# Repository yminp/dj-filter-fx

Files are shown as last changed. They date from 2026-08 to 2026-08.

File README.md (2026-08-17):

# dj-filter-fx
A voltage-controlled DJ filter unit with LFO-like envelope function

## Disclaimer
This design has not yet been validated with a physical prototype. The schematic has been reviewed and analyzed, but practical issues may still be discovered during assembly and testing. A prototype is planned to be built and tested soon.

Anyone building the current revision should treat it as an experimental, pre-prototype design rather than a fully validated production circuit.

## Description
This project is a standalone analog filter effects unit intended primarily for DJ use.

The motivation came from the relative lack of dedicated standalone filter FX units for DJs. Filter effects are built into most modern DJ mixers, but older analog mixers may not provide an integrated filter effect. In those cases, applying a filter generally requires an external effects processor connected through the mixer's send/return path. The goal of this project is therefore to provide a dedicated external filter effect that can be used with such mixers while retaining an analog signal path.

Another major purpose of the project was educational. I wanted to explore the use of operational transconductance amplifiers (OTAs), particularly the LM13700, as voltage-controlled amplifiers (VCAs). In this design, VCAs are used inside a state-variable filter to provide voltage control of both the filter's center frequency and resonance Q. This required treating the OTA not merely as a conventional variable-resistance element, but as a controllable transconductance stage whose gain can be incorporated into the state-variable filter equations.

The project consequently combines several topics that I wanted to study in a practical audio circuit:

- voltage-controlled state-variable filters;
- LM13700 OTA/VCA design;
- voltage control of cutoff frequency and resonance;
- envelope-controlled filtering;
- LFO-based filter modulation;
- analog switching and filter-mode selection;
- balanced audio input and output interfacing;
- gain structure and headroom for professional/DJ audio levels (accepting input up to +26dBu, balanced).

The design is intended both as a usable DJ effects unit and as an experimental platform for learning analog filter and voltage-controlled amplifier design.

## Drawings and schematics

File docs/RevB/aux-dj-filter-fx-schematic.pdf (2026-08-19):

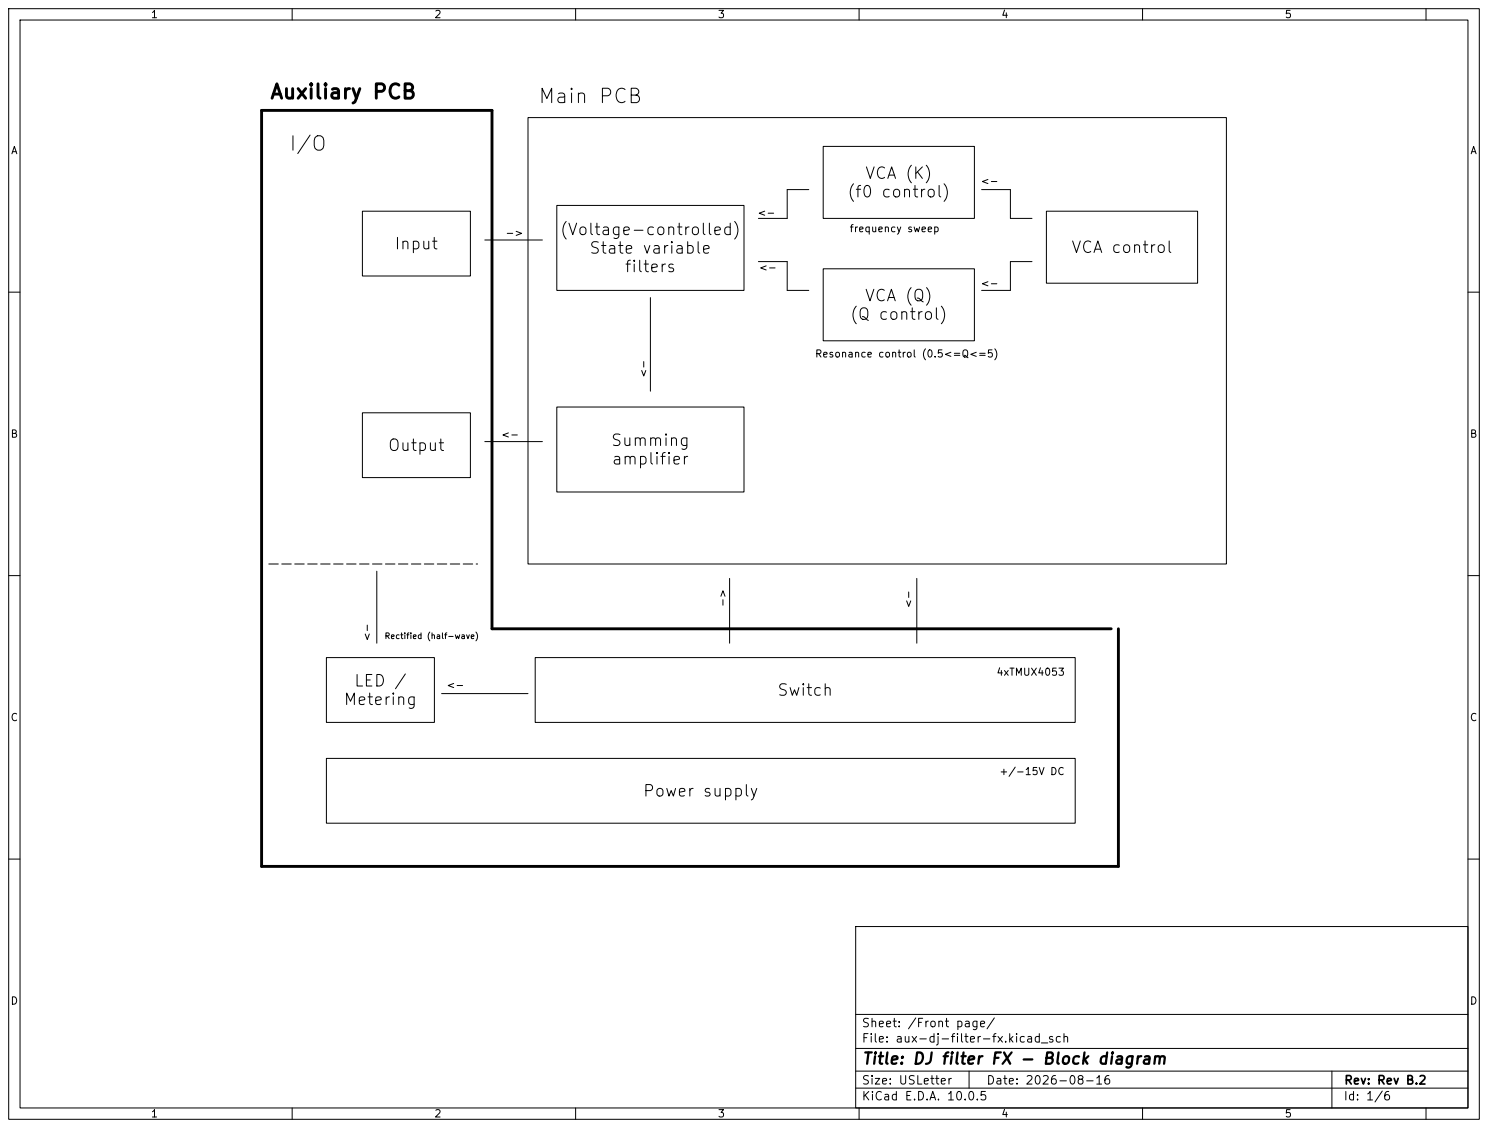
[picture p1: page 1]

Sheet: /Front page/
File: aux-dj-filter-fx.kicad_sch
Title: DJ filter FX - Block diagram

Size: USLetter | Rev: Rev B.2
KiCad E.D.A. 10.0.5 | Id: 1/6

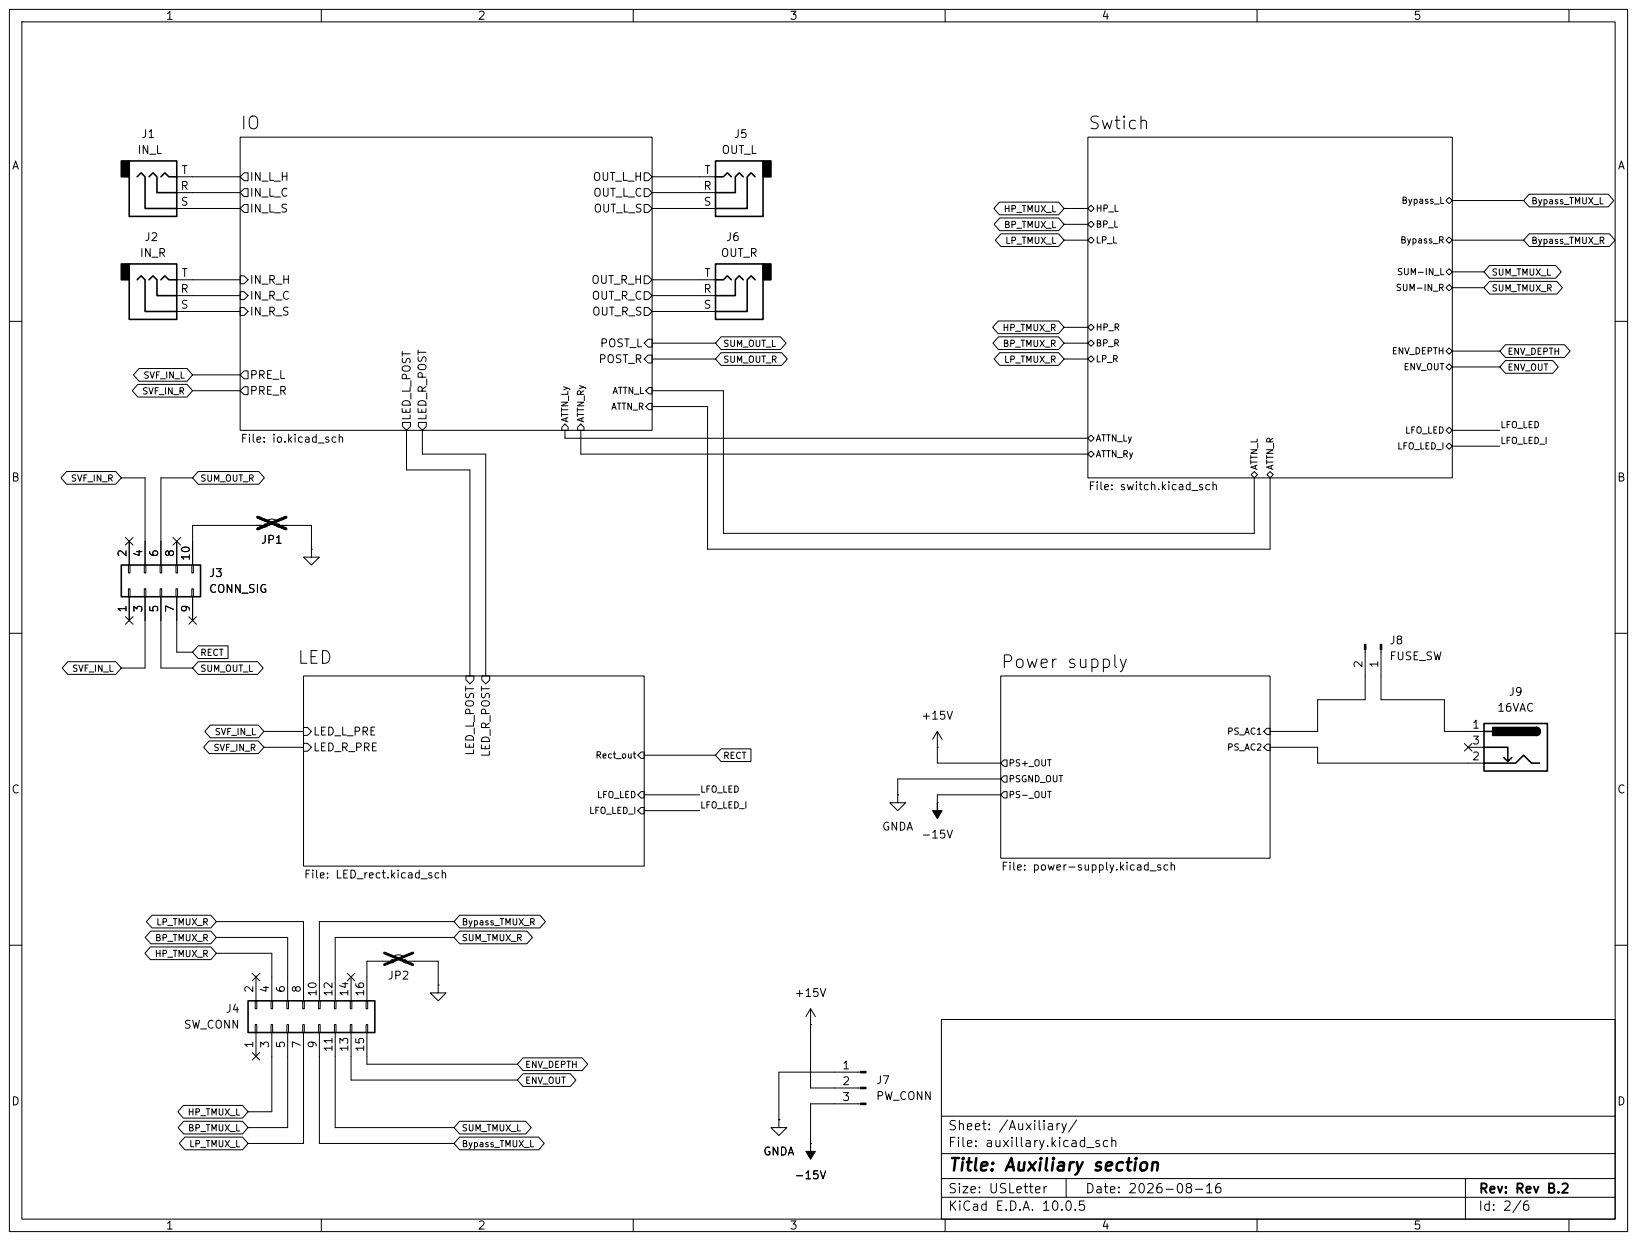
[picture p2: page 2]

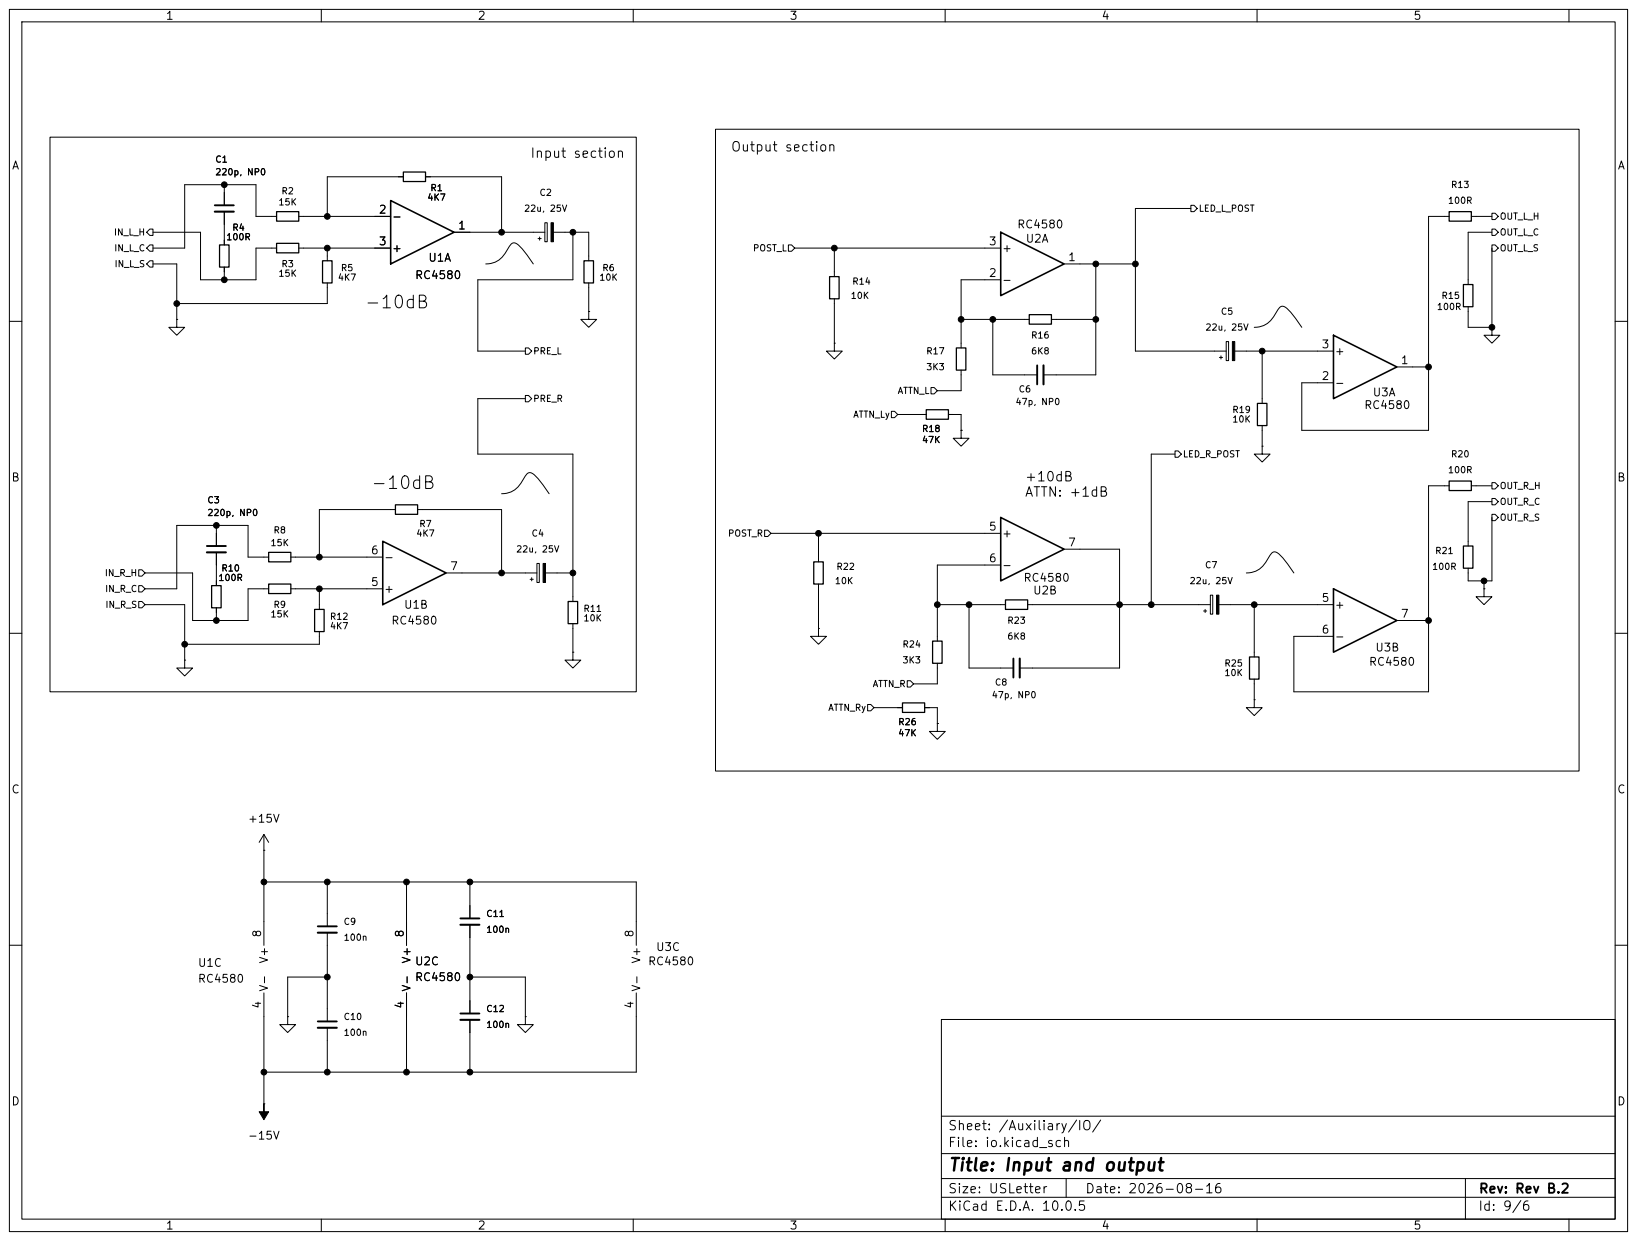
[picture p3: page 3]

File: io.kicad_sch
Title: Input and output

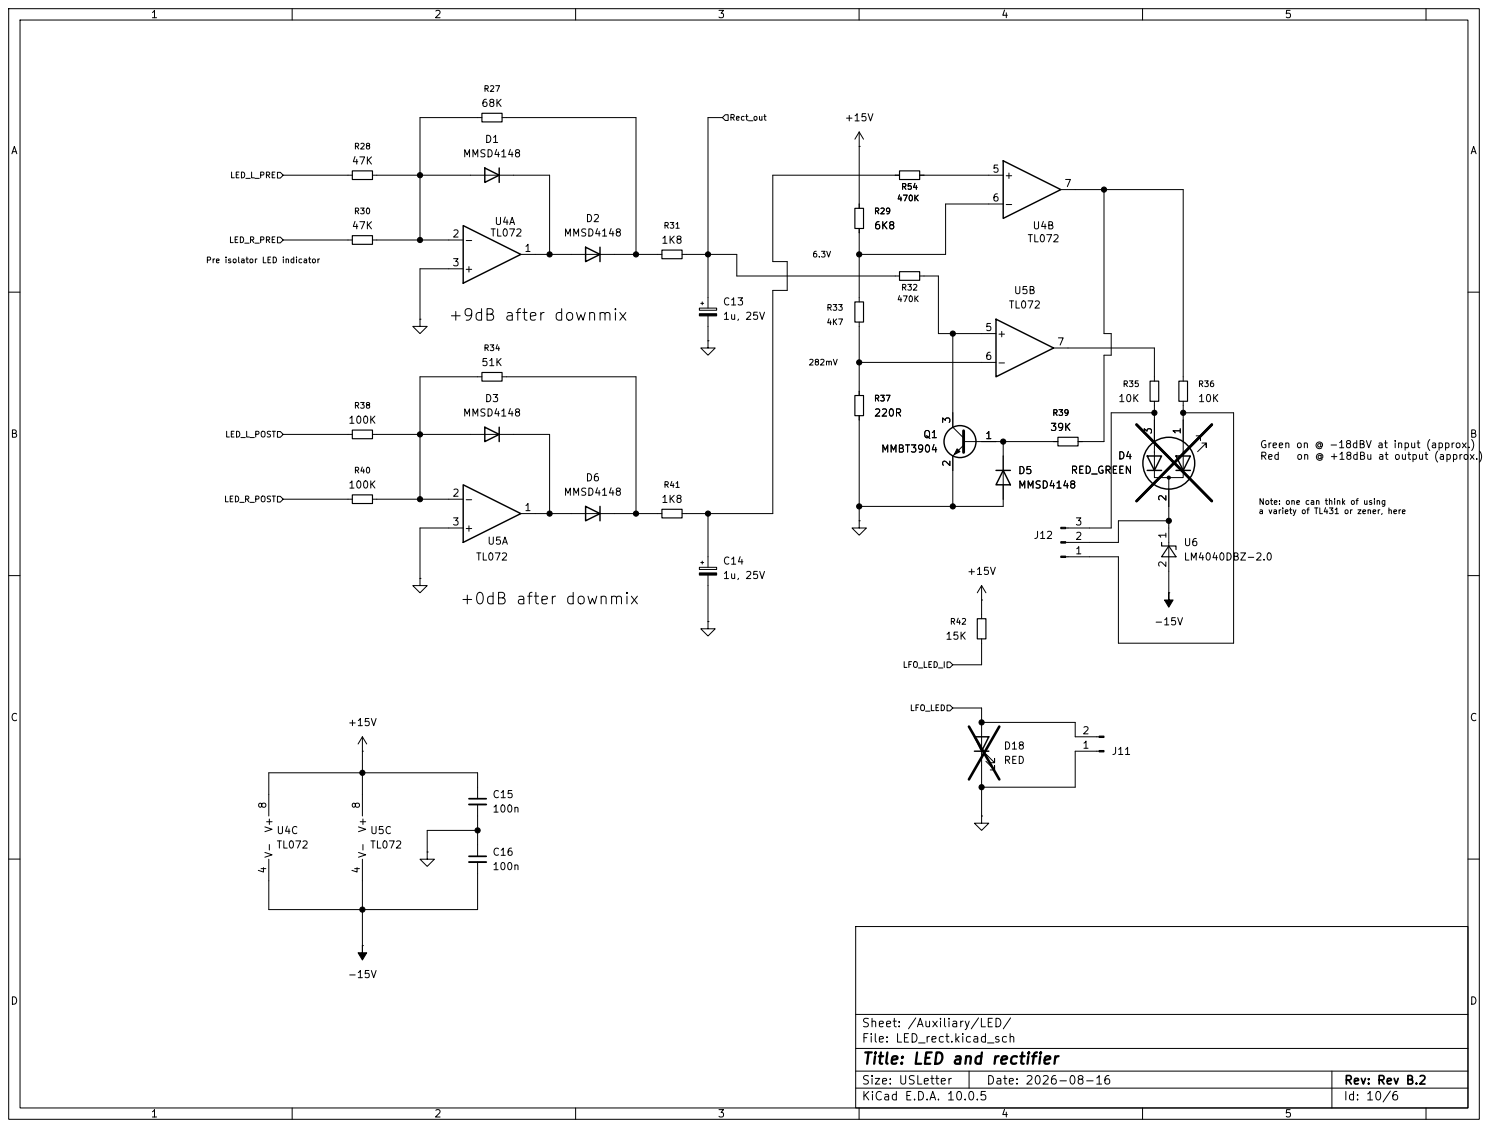
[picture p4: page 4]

File: LED_rect.kicad_sch
Title: LED and rectifier

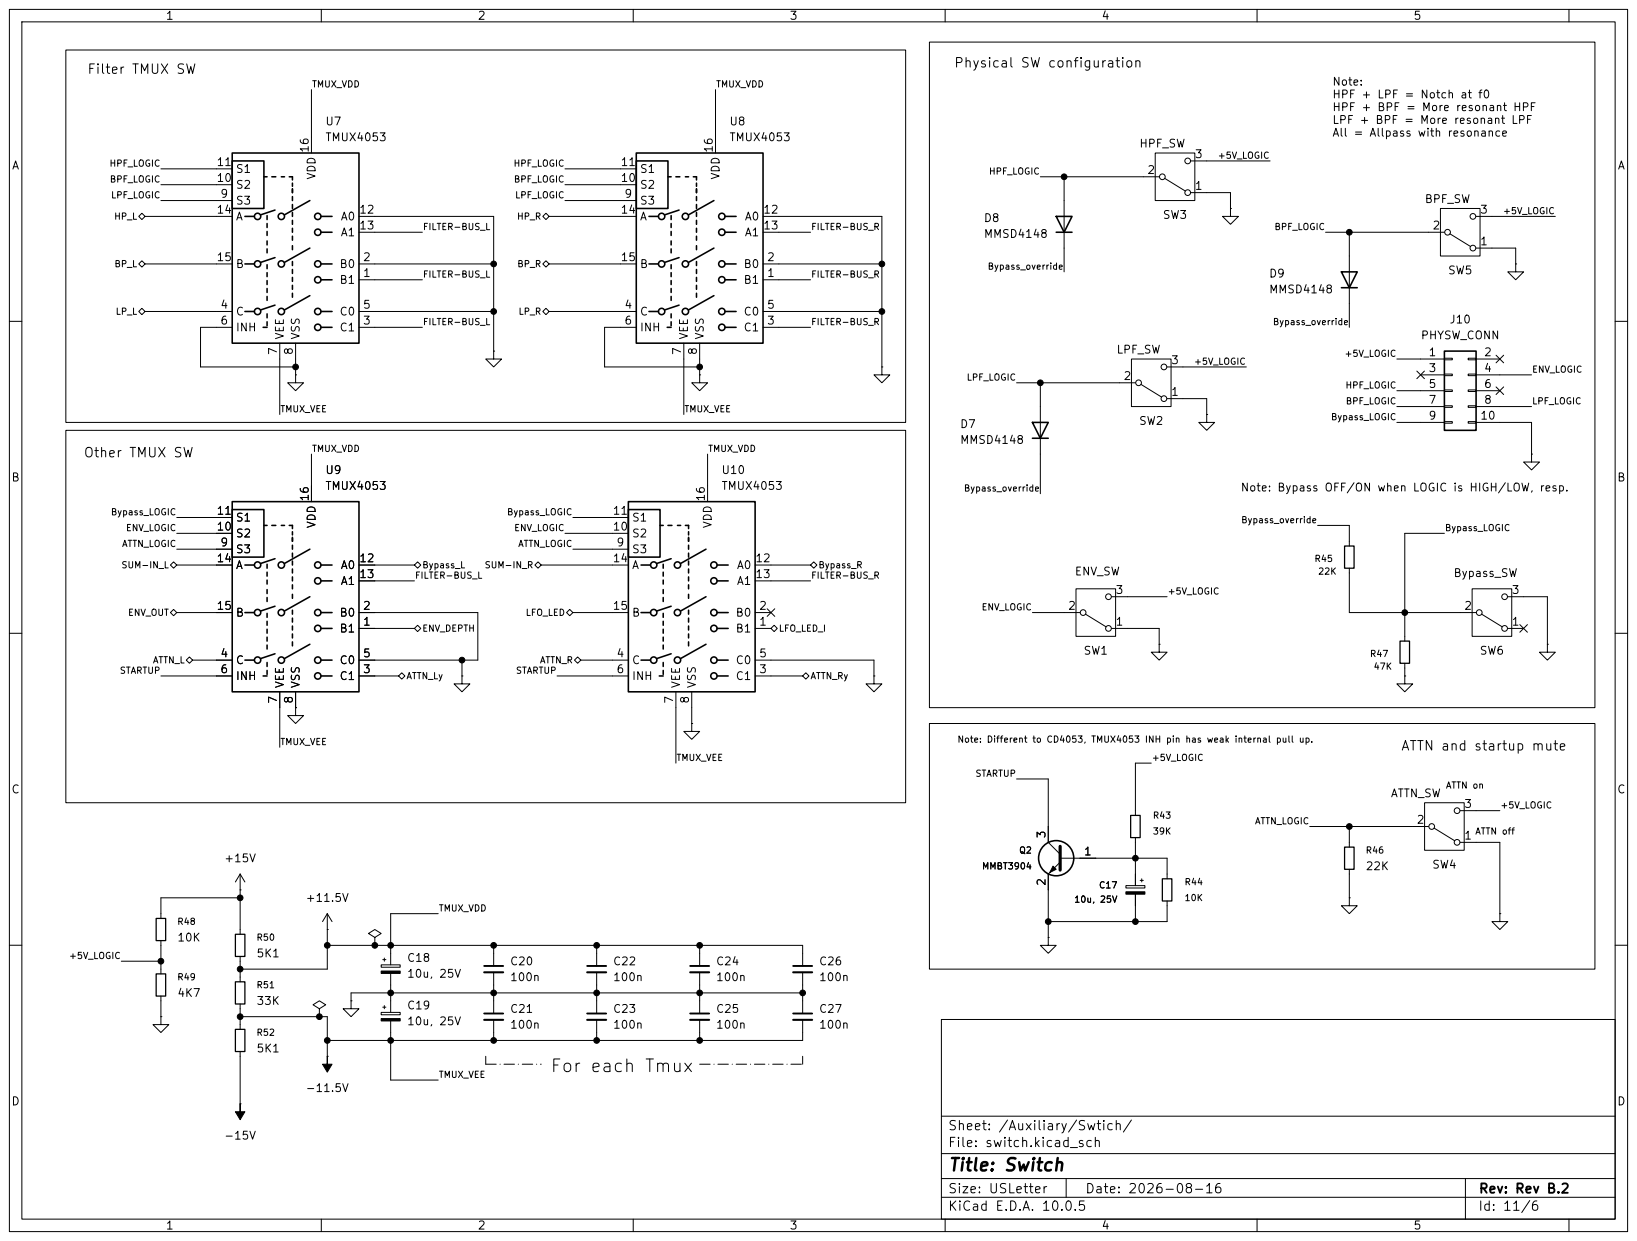
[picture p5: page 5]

Note: HPF + LPF = Notch at f0 HPF + BPF = More resonant HPF

All = Allpass with resonance Note: Bypass OFF/ON when LOGIC is HIGH/LOW, resp. C17

LPF + BPF = More resonant LPF

Note: Different to CD4053, TMUX4053 INH pin has weak internal pull up.

ATTN and startup mute

ATTN off ATTN on For each Tmux

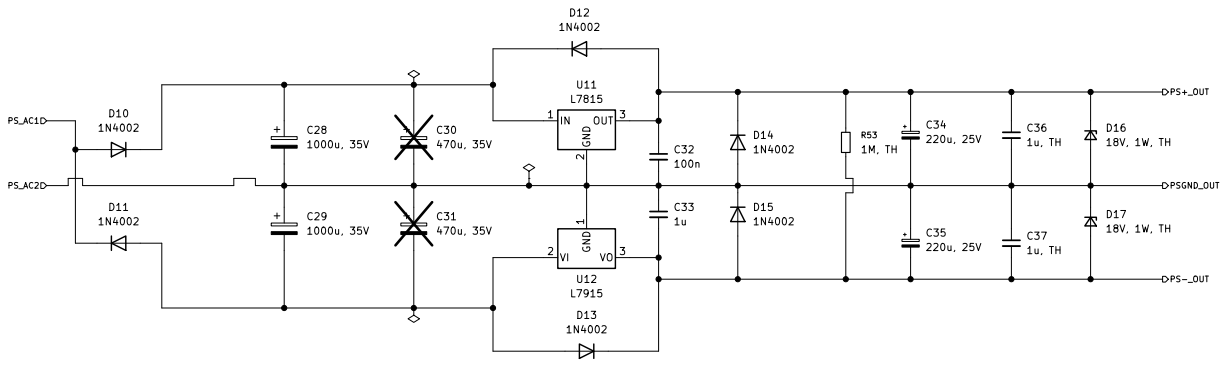
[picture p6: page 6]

Sheet: /Auxiliary/Power supply/
File: power-supply.kicad_sch
Title: Power supply

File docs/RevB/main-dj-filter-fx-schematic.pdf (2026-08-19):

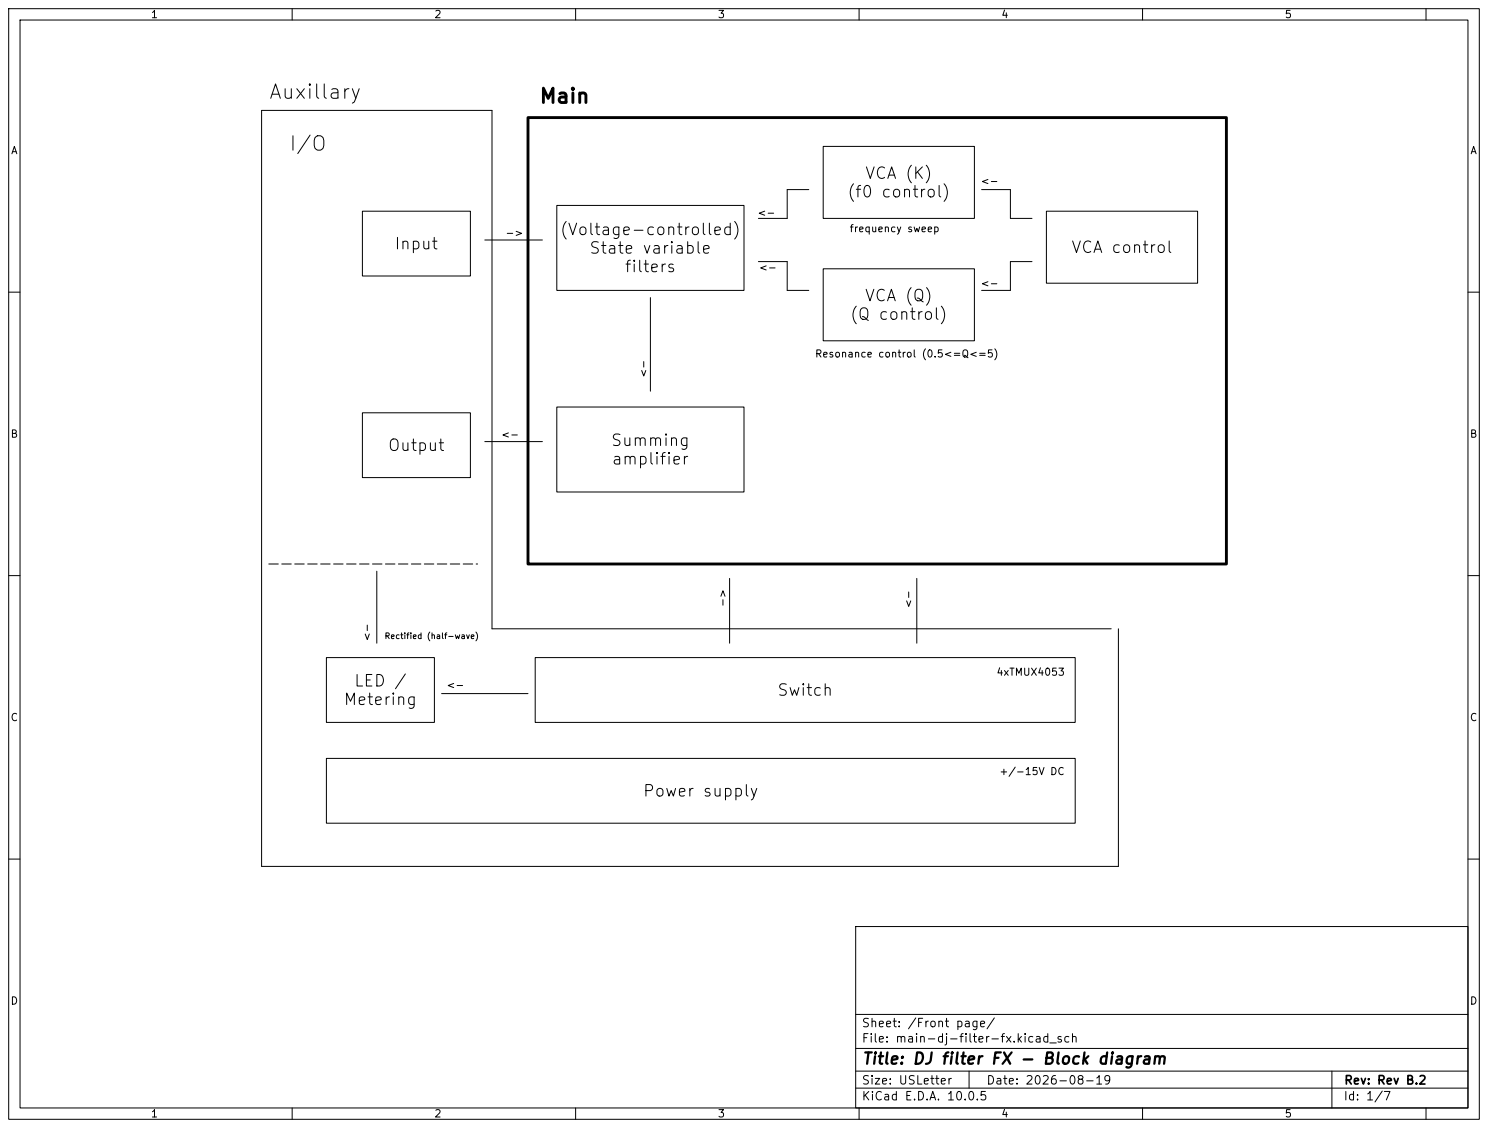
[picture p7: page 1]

Sheet: /Front page/
File: main-dj-filter-fx.kicad_sch
Title: DJ filter FX - Block diagram

Size: USLetter | Rev: Rev B.2
KiCad E.D.A. 10.0.5 | Id: 1/7

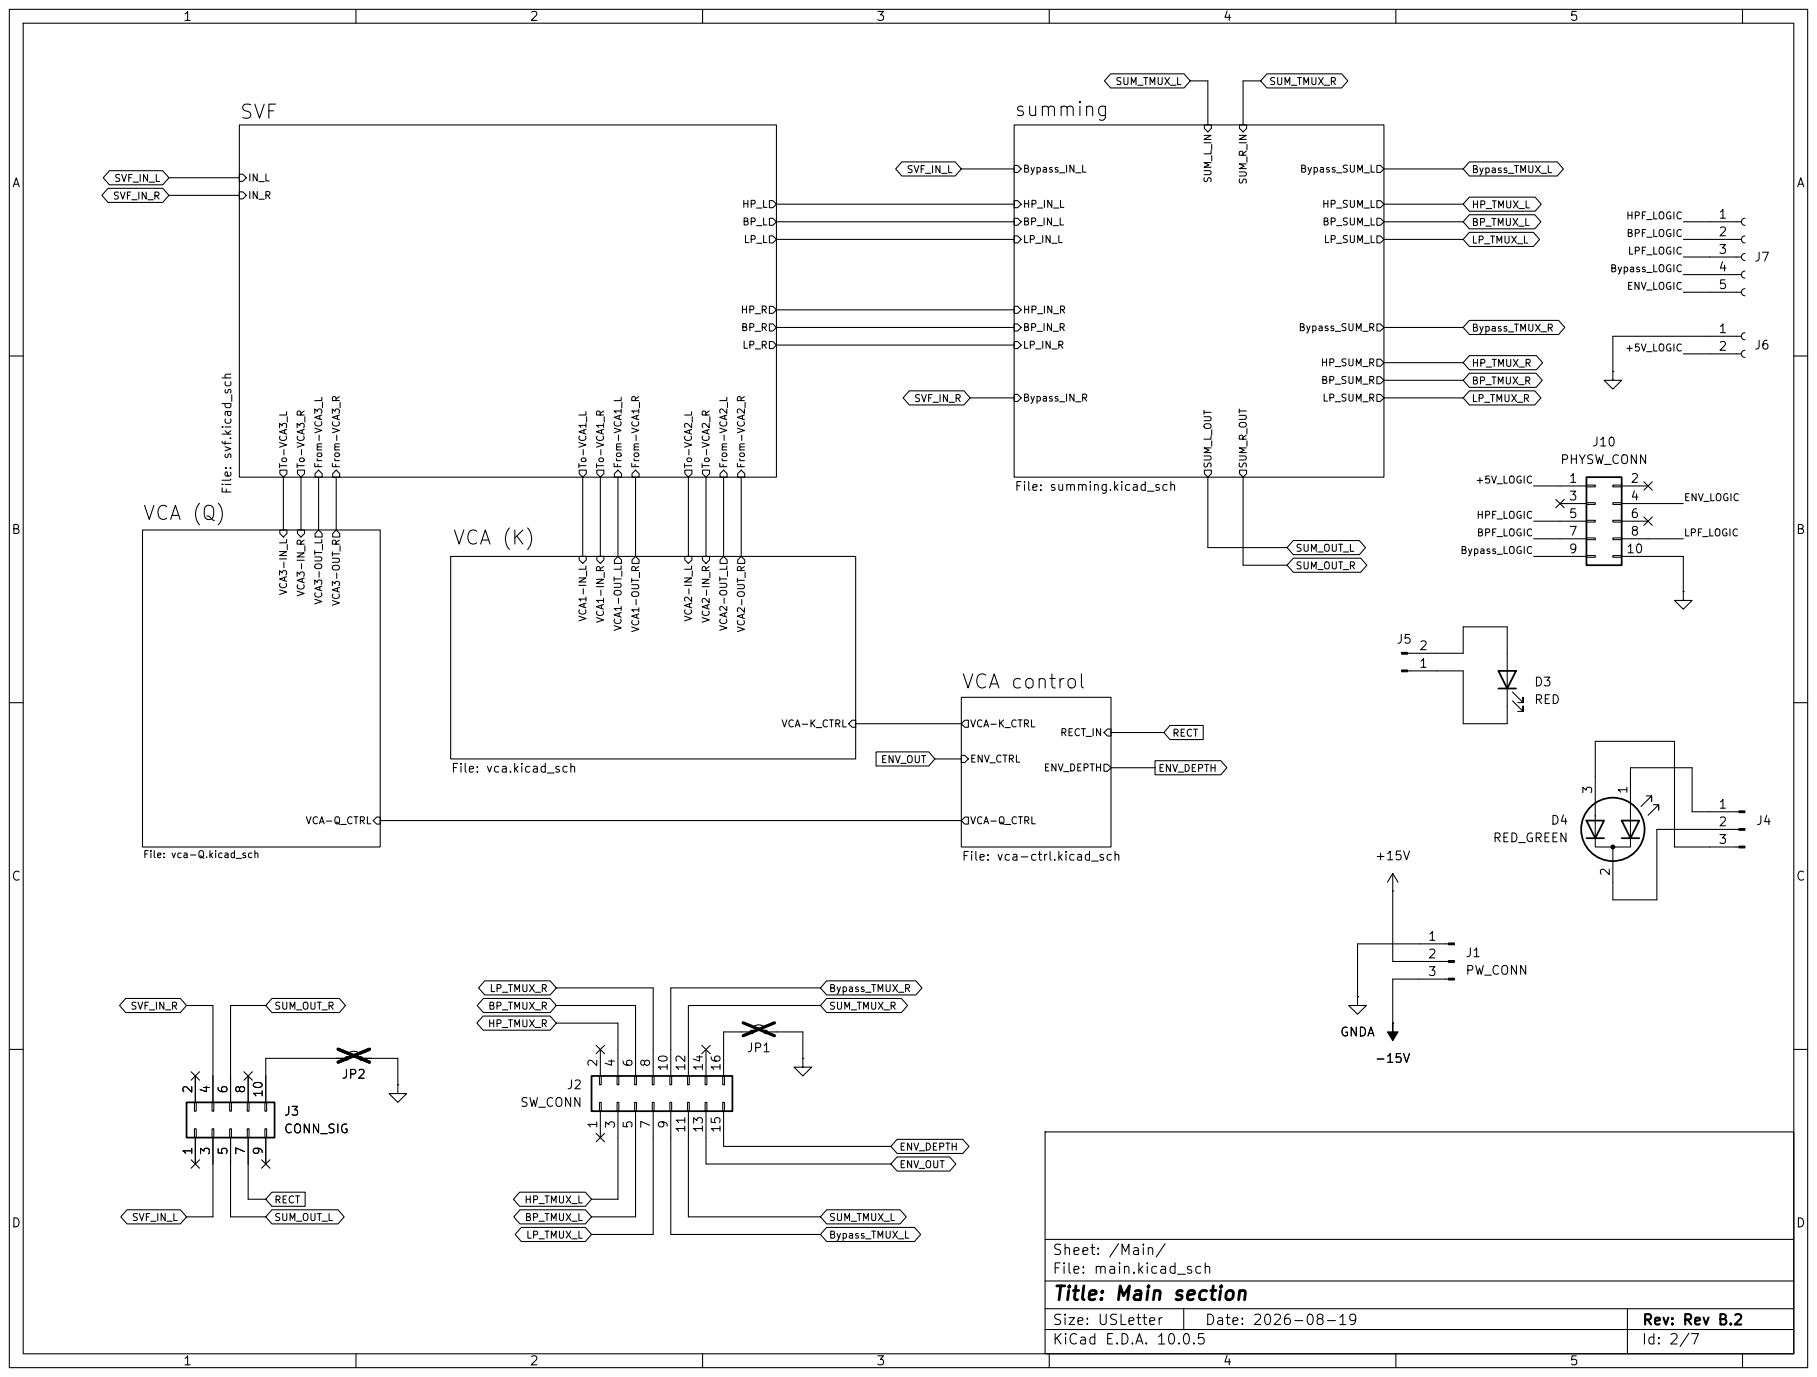
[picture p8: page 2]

RECT_IN VCA control File: vca-ctrl.kicad_sch
ENV_OUT

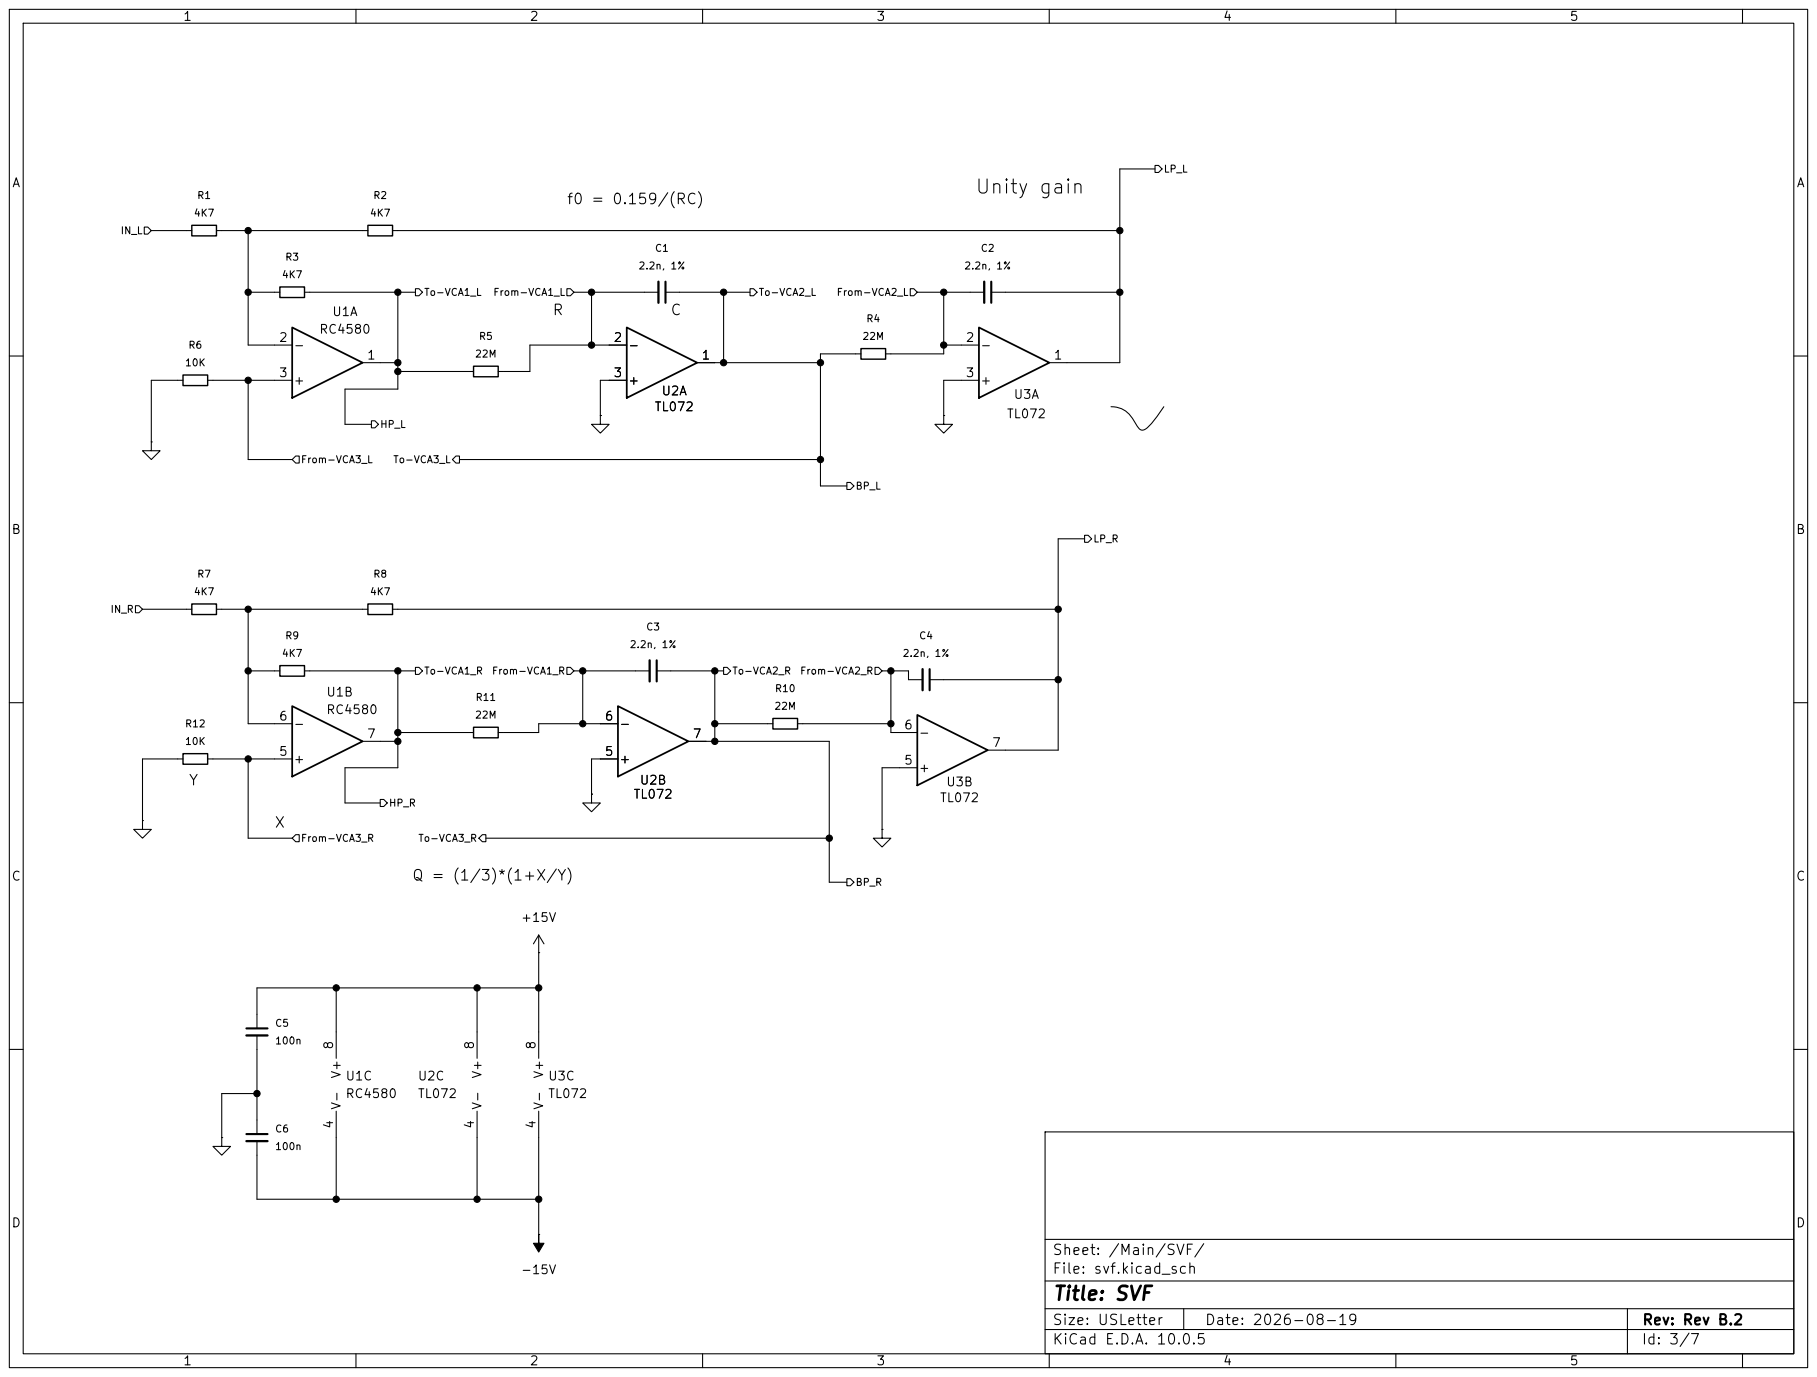
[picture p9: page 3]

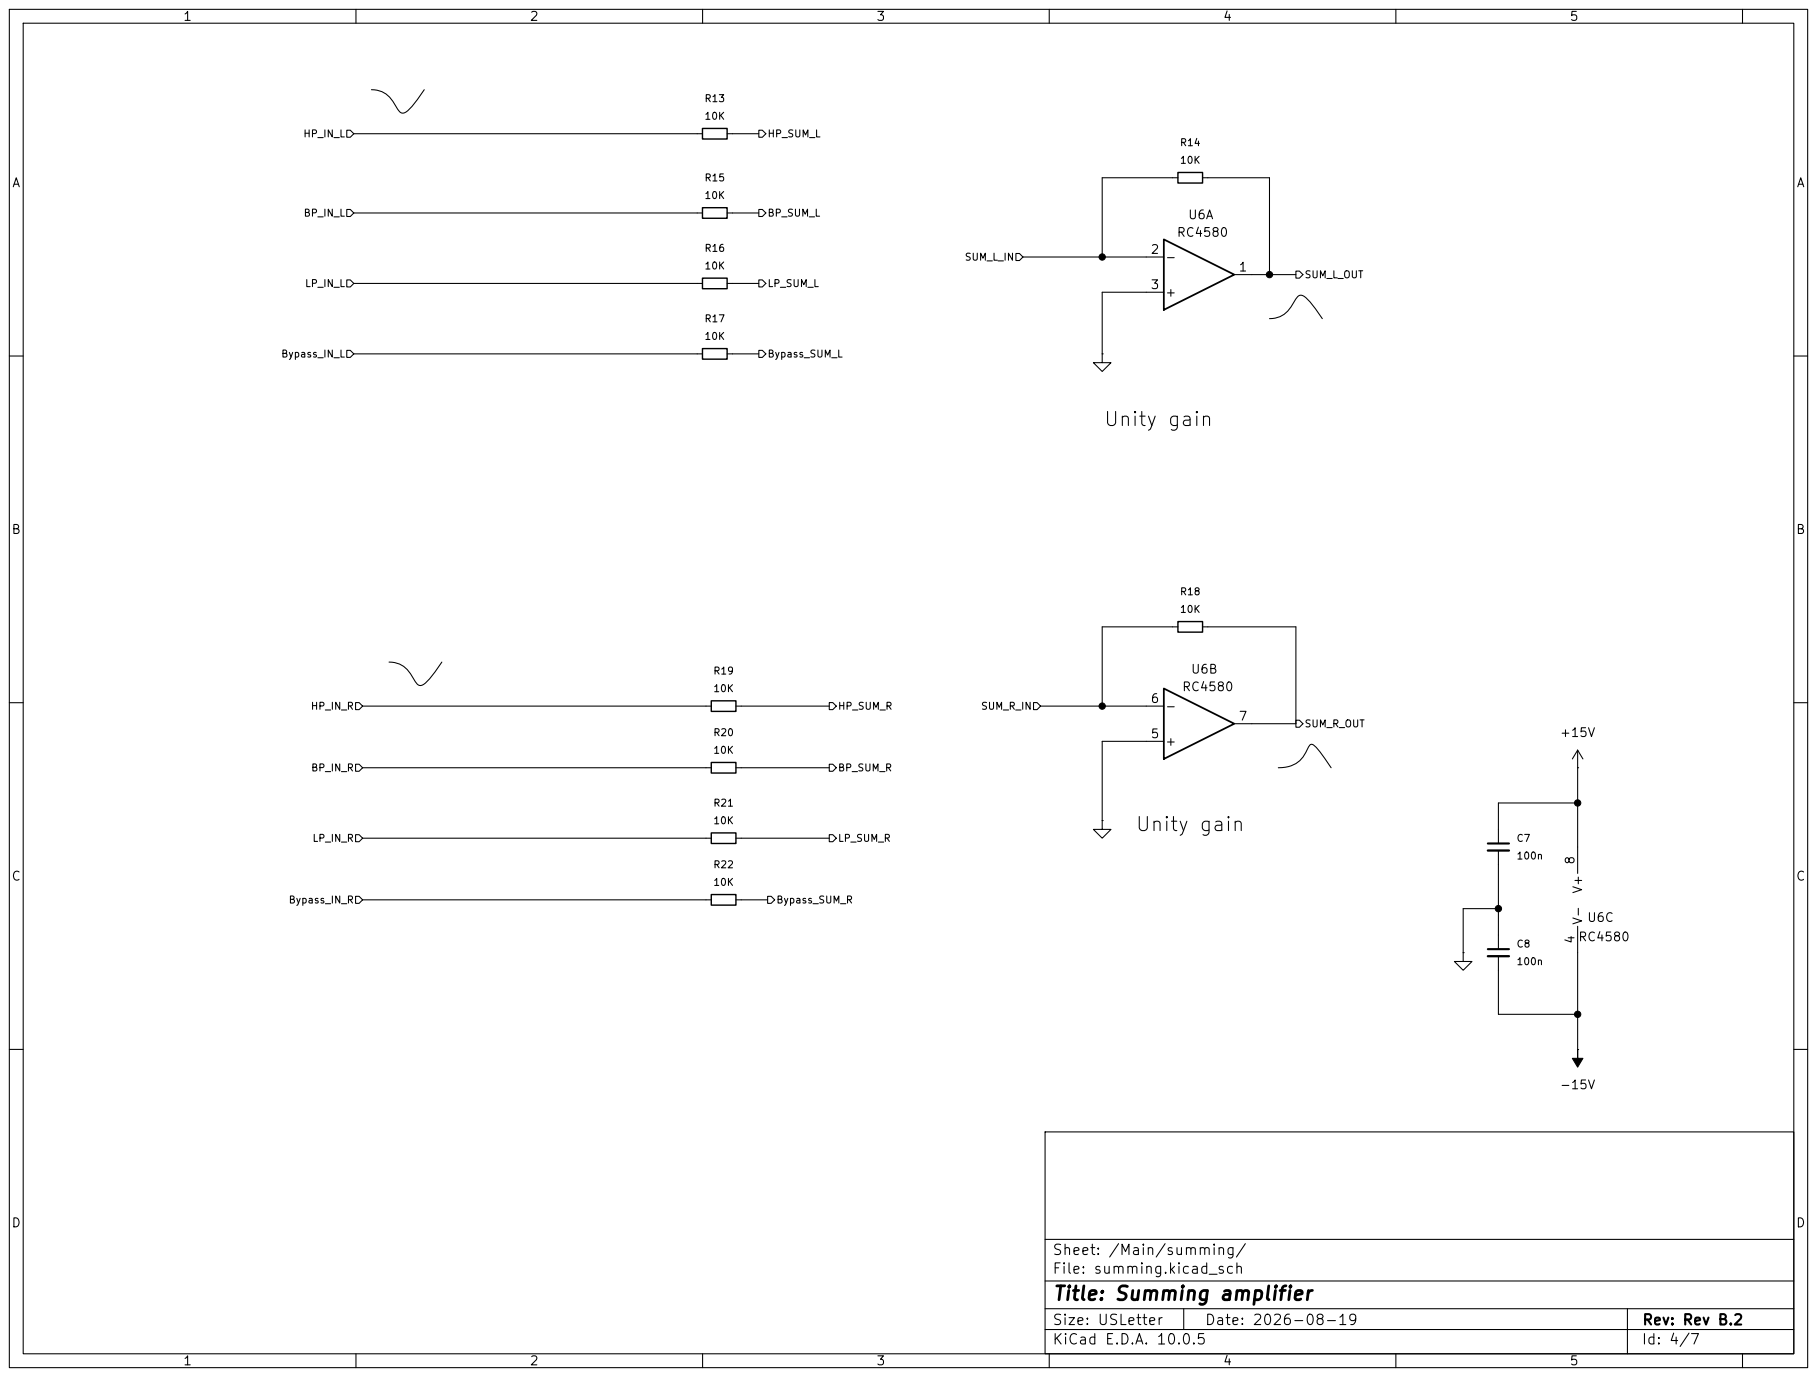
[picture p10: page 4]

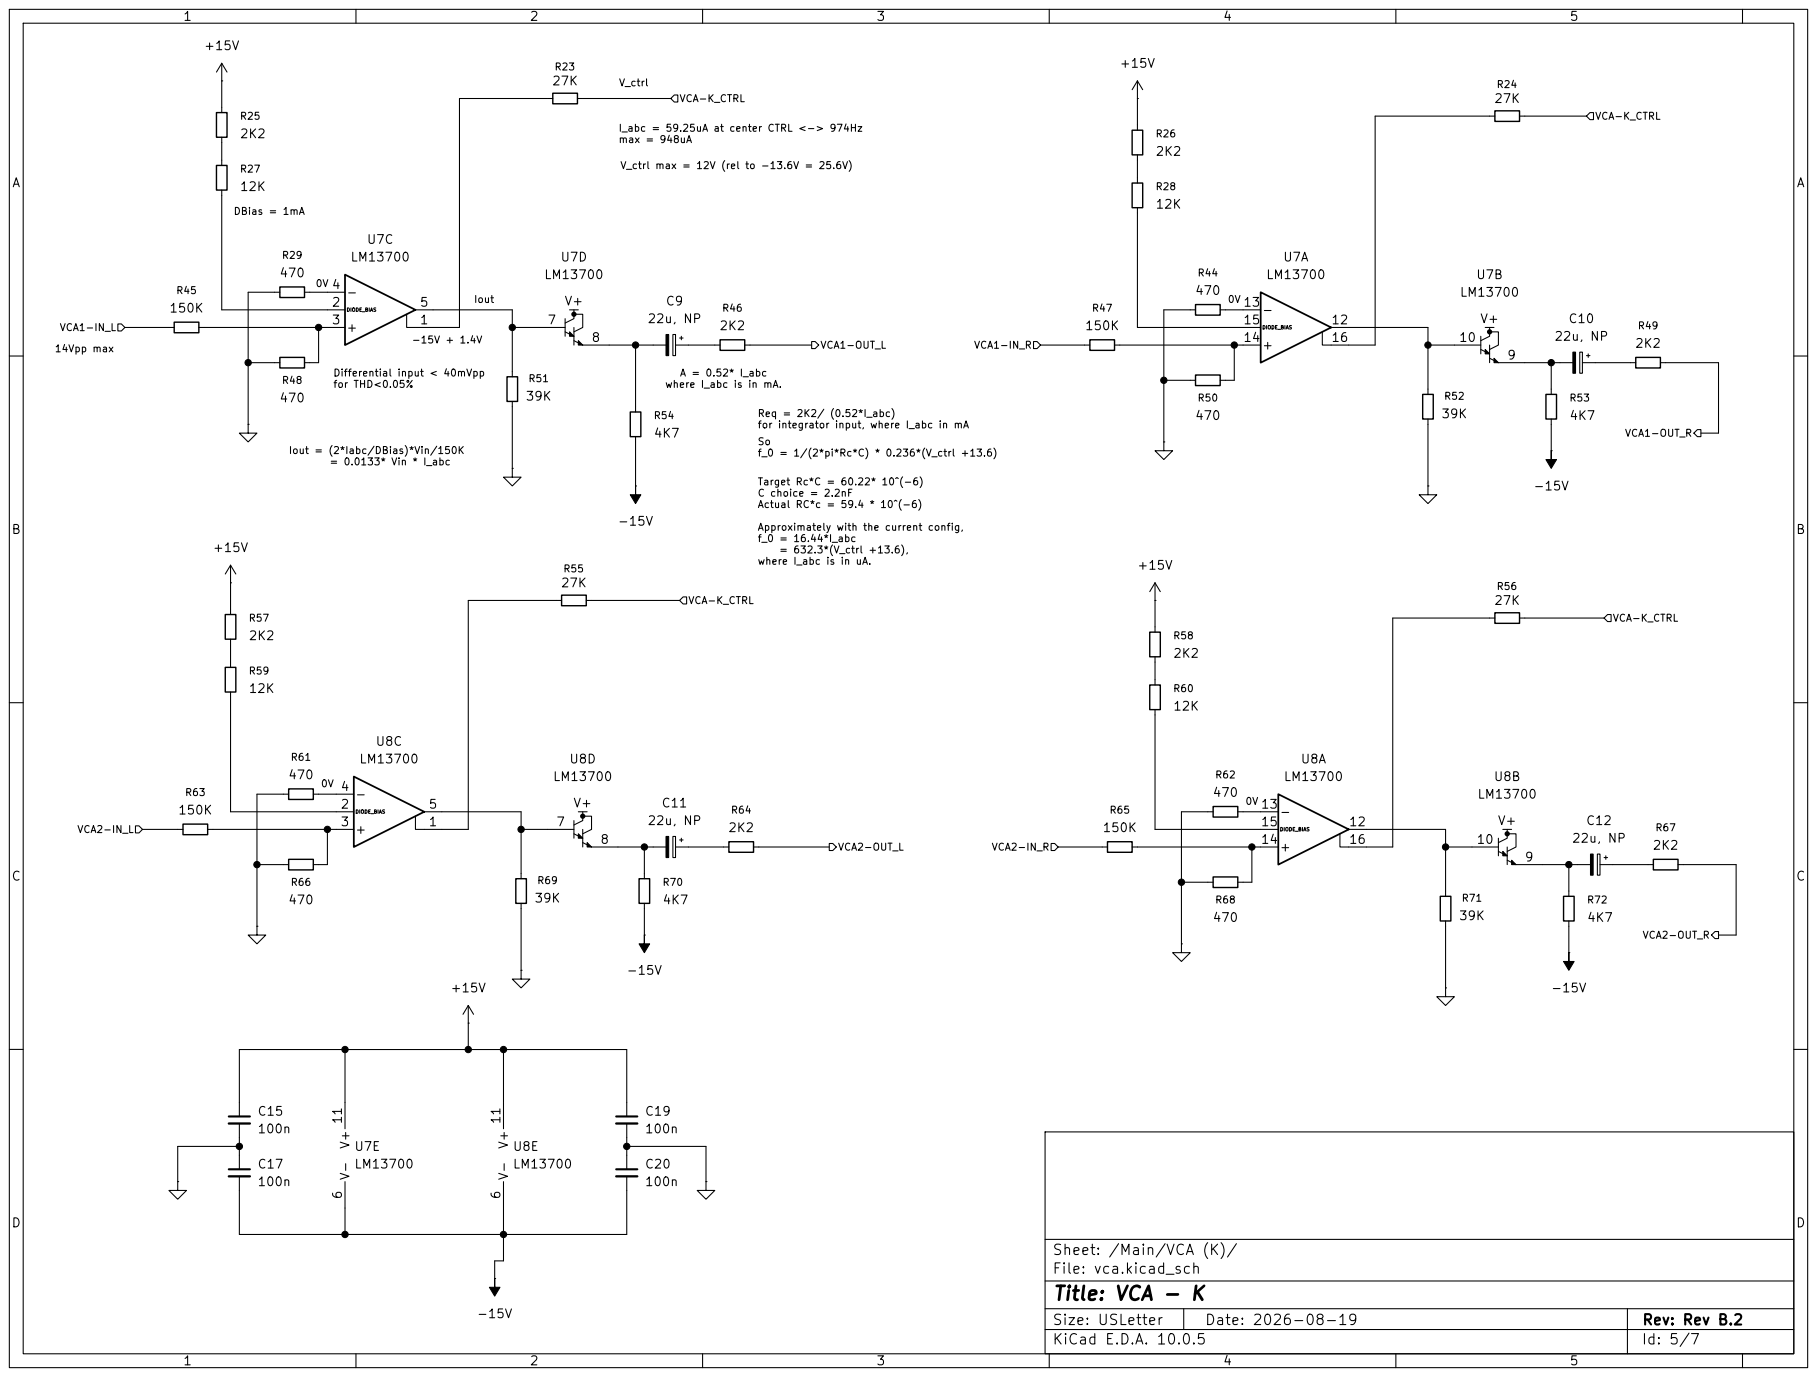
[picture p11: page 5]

f_0 = 1/(2*pi*Rc*C) * 0.236*(V_ctrl +13.6) V_ctrl max = 12V (rel to -13.6V = 25.6V) Req = 2K2/ (0.52*I_abc)

for integrator input, where I_abc in mA -15V + 1.4V

A = 0.52* I_abc where I_abc is in mA. Differential input < 40mVpp
for THD<0.05%

Iout = (2*Iabc/DBias)*Vin/150K = 0.0133* Vin * I_abc 0V

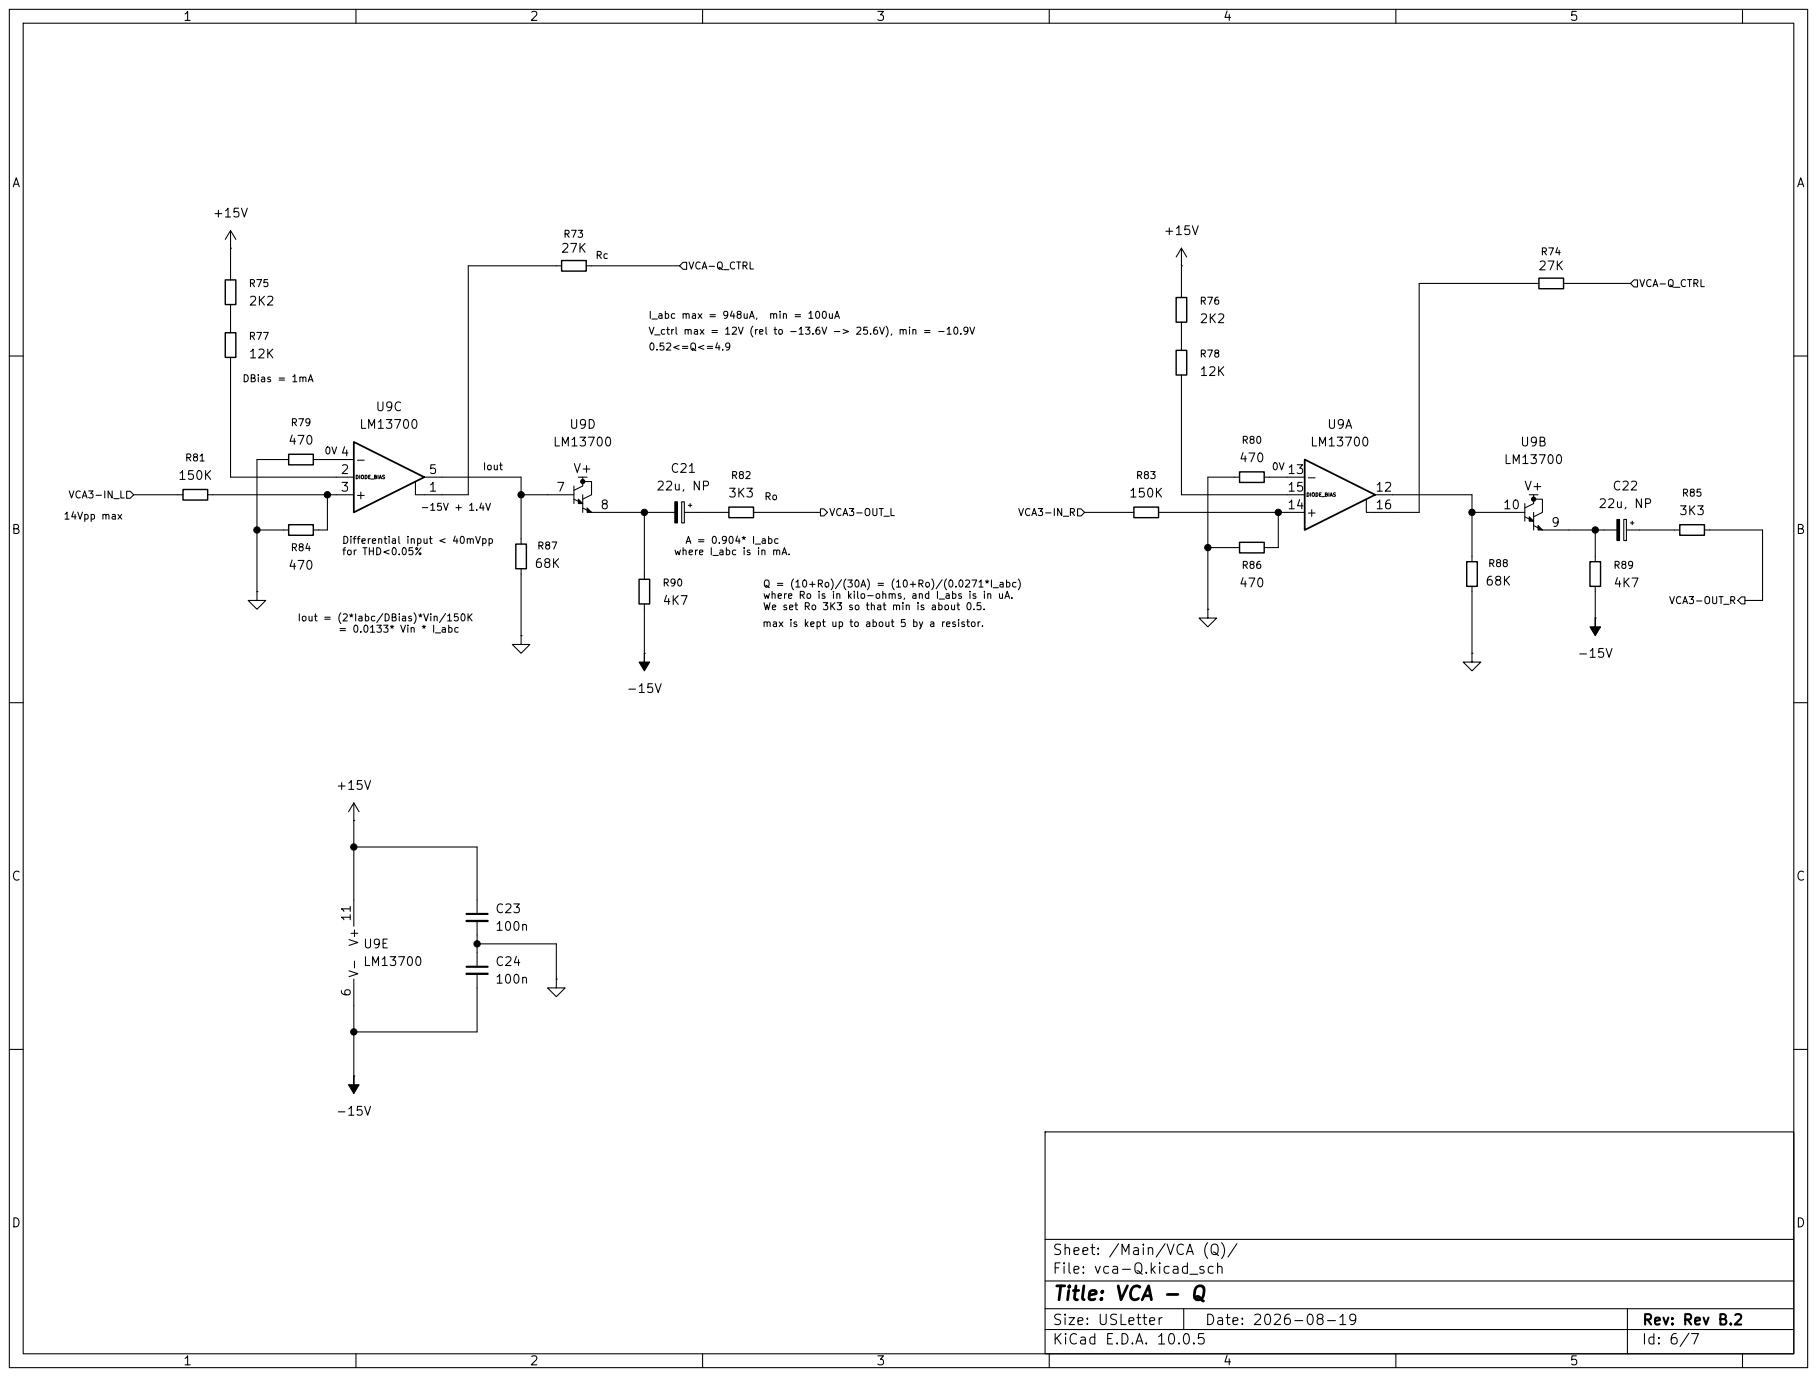
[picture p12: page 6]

V_ctrl max = 12V (rel to -13.6V -> 25.6V), min = -10.9V


Sheet: /Main/VCA control/
File: vca-ctrl.kicad_sch
Title: VCA control

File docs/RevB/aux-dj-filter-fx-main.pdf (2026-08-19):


Layout is provided by Quilter and manually modified
For Deeveci 158x90x60mm enclosure available on AliExpress

Sheet:
File: aux-dj-filter-fx.kicad_pcb
Title: Auxiliary board - DJ filter FX unit

Size: A4 | Rev: Rev A
KiCad E.D.A. 10.0.5 | Id: 1/9


Layout is provided by Quilter and manually modified
For Deeveci 158x90x60mm enclosure available on AliExpress

Sheet:
File: aux-dj-filter-fx.kicad_pcb
Title: Auxiliary board - DJ filter FX unit


Layout is provided by Quilter and manually modified
For Deeveci 158x90x60mm enclosure available on AliExpress

Sheet:
File: aux-dj-filter-fx.kicad_pcb
Title: Auxiliary board - DJ filter FX unit


Layout is provided by Quilter and manually modified
For Deeveci 158x90x60mm enclosure available on AliExpress

Sheet:
File: aux-dj-filter-fx.kicad_pcb
Title: Auxiliary board - DJ filter FX unit


Layout is provided by Quilter and manually modified
For Deeveci 158x90x60mm enclosure available on AliExpress

Sheet:
File: aux-dj-filter-fx.kicad_pcb
Title: Auxiliary board - DJ filter FX unit

Layout is provided by Quilter and manually modified
For Deeveci 158x90x60mm enclosure available on AliExpress

Sheet:
File: aux-dj-filter-fx.kicad_pcb
Title: Auxiliary board - DJ filter FX unit


Layout is provided by Quilter and manually modified
For Deeveci 158x90x60mm enclosure available on AliExpress

Sheet:
File: aux-dj-filter-fx.kicad_pcb
Title: Auxiliary board - DJ filter FX unit


Layout is provided by Quilter and manually modified
For Deeveci 158x90x60mm enclosure available on AliExpress

Sheet:
File: aux-dj-filter-fx.kicad_pcb
Title: Auxiliary board - DJ filter FX unit


Layout is provided by Quilter and manually modified
For Deeveci 158x90x60mm enclosure available on AliExpress

Sheet:
File: aux-dj-filter-fx.kicad_pcb
Title: Auxiliary board - DJ filter FX unit

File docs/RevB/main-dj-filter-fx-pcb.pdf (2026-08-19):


Layout is provided by Quilter and manually modified

Sheet:
File: main-dj-filter-fx.kicad_pcb
Title: Main PCB

Size: A4 | Rev: Rev B
KiCad E.D.A. 10.0.5 | Id: 1/9


Layout is provided by Quilter and manually modified

Sheet:
File: main-dj-filter-fx.kicad_pcb
Title: Main PCB


Layout is provided by Quilter and manually modified

Sheet:
File: main-dj-filter-fx.kicad_pcb
Title: Main PCB


Layout is provided by Quilter and manually modified

Sheet:
File: main-dj-filter-fx.kicad_pcb
Title: Main PCB


Layout is provided by Quilter and manually modified

Sheet:
File: main-dj-filter-fx.kicad_pcb
Title: Main PCB

Layout is provided by Quilter and manually modified

Sheet:
File: main-dj-filter-fx.kicad_pcb
Title: Main PCB


Layout is provided by Quilter and manually modified

Sheet:
File: main-dj-filter-fx.kicad_pcb
Title: Main PCB


Layout is provided by Quilter and manually modified

Sheet:
File: main-dj-filter-fx.kicad_pcb
Title: Main PCB


Layout is provided by Quilter and manually modified

Sheet:
File: main-dj-filter-fx.kicad_pcb
Title: Main PCB

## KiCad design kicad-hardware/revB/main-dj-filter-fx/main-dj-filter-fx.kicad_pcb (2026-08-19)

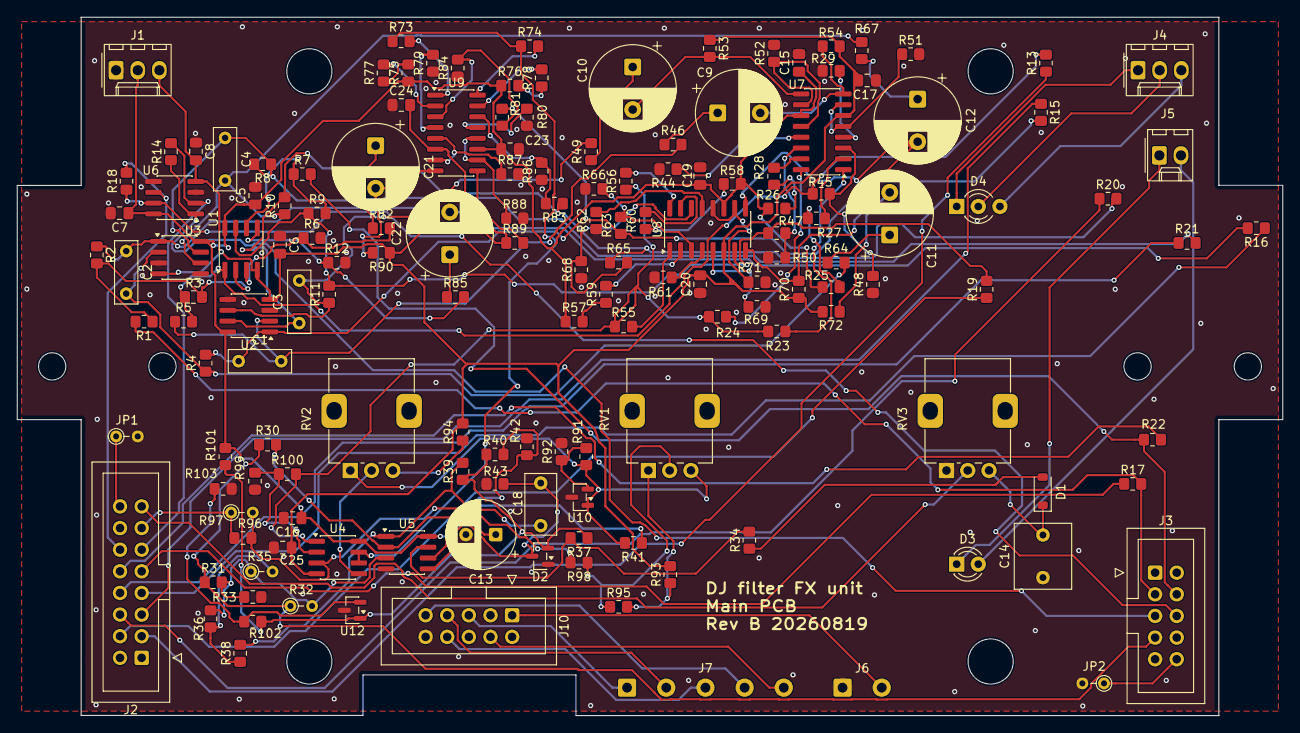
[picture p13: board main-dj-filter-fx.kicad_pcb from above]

Board: 2 copper layers, 148.6 x 82.0 mm, 156 parts (0 on the bottom side), 116 nets.

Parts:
C1, C2, C3, C4: 2.2n, 1%; C_Rect_L7.2mm_W2.5mm_P5.00mm
C5, C6, C7, C8, C15, C16, C17, C19, C20, C23, C24, C25: 100n; C_0805_2012Metric_Pad1.18x1.45mm_HandSolder
C9, C10, C11, C12, C21, C22: 22u, NP; CP_Radial_D10.0mm_P5.00mm
C13: 10u, NP; CP_Radial_D8.0mm_P3.50mm
C14: 1u, film; C_Rect_L7.5mm_W6.5mm_P5.00mm
C18: 100n, film; C_Rect_L7.0mm_W3.5mm_P5.00mm
D1: MMSD4148; D_SOD-123
D2: BAT54S; SOT-23
D3: RED; LED_D3.0mm
D4: RED_GREEN; LED_D3.0mm-3
J1: PW_CONN; Molex_KK-254_AE-6410-03A_1x03_P2.54mm_Vertical
J2: SW_CONN; IDC-Header_2x08_P2.54mm_Vertical
J3: CONN_SIG; IDC-Header_2x05_P2.54mm_Vertical
J4: LED2color_CONN; Molex_KK-254_AE-6410-03A_1x03_P2.54mm_Vertical
J5: LED; Molex_KK-254_AE-6410-02A_1x02_P2.54mm_Vertical
J6: Conn_01x02_Socket; SolderWire-0.5sqmm_1x02_P4.6mm_D0.9mm_OD2.1mm
J7: Conn_01x05_Socket; SolderWire-0.5sqmm_1x05_P4.6mm_D0.9mm_OD2.1mm
J10: PHYSW_CONN; IDC-Header_2x05_P2.54mm_Vertical
JP1, JP2: Jumper_2_Small_Open; R_Axial_DIN0204_L3.6mm_D1.6mm_P2.54mm_Vertical
R1, R2, R3, R7, R8, R9, R37, R39, R53, R54, R70, R72, R89, R90: 4K7; R_0805_2012Metric_Pad1.20x1.40mm_HandSolder
R4, R5, R10, R11: 22M; R_0805_2012Metric_Pad1.20x1.40mm_HandSolder
R6, R12, R13, R14, R15, R16, R17, R18, R19, R20, R21, R22, R42, R102, R103: 10K; R_0805_2012Metric_Pad1.20x1.40mm_HandSolder
R23, R24, R55, R56, R73, R74: 27K; R_0805_2012Metric_Pad1.20x1.40mm_HandSolder
R25, R26, R46, R49, R57, R58, R64, R67, R75, R76, R92, R101: 2K2; R_0805_2012Metric_Pad1.20x1.40mm_HandSolder
R27, R28, R59, R60, R77, R78: 12K; R_0805_2012Metric_Pad1.20x1.40mm_HandSolder
R29, R44, R48, R50, R61, R62, R66, R68, R79, R80, R84, R86: 470; R_0805_2012Metric_Pad1.20x1.40mm_HandSolder
R30, R98: 220K; R_0805_2012Metric_Pad1.20x1.40mm_HandSolder
R31: 47K; R_0805_2012Metric_Pad1.20x1.40mm_HandSolder
R32: 100K, TH; R_Axial_DIN0204_L3.6mm_D1.6mm_P2.54mm_Vertical
R33, R99: 100K; R_0805_2012Metric_Pad1.20x1.40mm_HandSolder
R34: 1K; R_0805_2012Metric_Pad1.20x1.40mm_HandSolder
R35: 1M, TH; R_Axial_DIN0204_L3.6mm_D1.6mm_P2.54mm_Vertical
R36: 10R; R_0805_2012Metric_Pad1.20x1.40mm_HandSolder
R38: 1M; R_0805_2012Metric_Pad1.20x1.40mm_HandSolder
R40, R51, R52, R69, R71: 39K; R_0805_2012Metric_Pad1.20x1.40mm_HandSolder
R41: 680R; R_0805_2012Metric_Pad1.20x1.40mm_HandSolder
R43, R87, R88, R100: 68K; R_0805_2012Metric_Pad1.20x1.40mm_HandSolder
R45, R47, R63, R65, R81, R83: 150K; R_0805_2012Metric_Pad1.20x1.40mm_HandSolder
R82, R85: 3K3; R_0805_2012Metric_Pad1.20x1.40mm_HandSolder
R91: 8K2; R_0805_2012Metric_Pad1.20x1.40mm_HandSolder
R93: 5K6; R_0805_2012Metric_Pad1.20x1.40mm_HandSolder
R94: 18K; R_0805_2012Metric_Pad1.20x1.40mm_HandSolder
R95: 33K; R_0805_2012Metric_Pad1.20x1.40mm_HandSolder
R96: 330K; R_0805_2012Metric_Pad1.20x1.40mm_HandSolder
R97: 680K, TH; R_Axial_DIN0204_L3.6mm_D1.6mm_P2.54mm_Vertical
RV1, RV2, RV3: 100KA; Potentiometer_Alps_RK09K_Single_Vertical
U1, U6: RC4580; SOIC-8_3.9x4.9mm_P1.27mm
U2, U3: TL072; SOIC-8_3.9x4.9mm_P1.27mm
U4: LM358; SOIC-8_3.9x4.9mm_P1.27mm
U5: LM2903; SOIC-8_3.9x4.9mm_P1.27mm
U7, U8, U9: LM13700; SOIC-16_3.9x9.9mm_P1.27mm
U10: TL431; SOT-23
U12: TL431DBZ; SOT-23

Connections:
+15V: C5.1, C7.1, C15.1, C16.1, C19.1, C23.1, J1.2, R25.1, R26.1, R41.1, R57.1, R58.1, R75.1, R76.1, R101.1, U1.8 (V+), U2.8 (V+), U3.8 (V+), U4.8 (V+), U5.8 (V+), U6.8 (V+), U7.11 (V+), U8.11 (V+), U9.11 (V+)
-15V: C6.2, C8.2, C17.2, C20.2, C24.2, C25.2, J1.3, R53.1, R54.1, R70.1, R72.1, R89.1, R90.1, R93.2, R94.2, U1.4 (V-), U2.4 (V-), U3.4 (V-), U4.4 (V-), U6.4 (V-), U7.6 (V-), U8.6 (V-), U9.6 (V-)
/Main/+5V_LOGIC: J6.2, J10.1
/Main/BPF_LOGIC: J7.2, J10.7
/Main/Bypass_LOGIC: J7.4, J10.9
/Main/ENV_LOGIC: J7.5, J10.4
/Main/HPF_LOGIC: J7.1, J10.5
/Main/LPF_LOGIC: J7.3, J10.8
/Main/SVF/BP_L: C1.1, R4.2, R15.2, R63.1, R81.1, U2.1
/Main/SVF/BP_R: C3.1, R10.2, R20.2, R65.1, R83.1, U2.7
/Main/SVF/From-VCA1_L: C1.2, R5.1, R46.2, U2.2 (-)
/Main/SVF/From-VCA1_R: C3.2, R11.1, R49.2, U2.6 (-)
/Main/SVF/From-VCA2_L: C2.2, R4.1, R64.2, U3.2 (-)
/Main/SVF/From-VCA2_R: C4.2, R10.1, R67.2, U3.6 (-)
/Main/SVF/From-VCA3_L: R6.1, R82.2, U1.3 (+)
/Main/SVF/From-VCA3_R: R12.1, R85.2, U1.5 (+)
/Main/SVF/HP_L: R3.1, R5.2, R13.2, R45.1, U1.1
/Main/SVF/HP_R: R9.1, R11.2, R19.2, R47.1, U1.7
/Main/SVF/LP_L: C2.1, R2.1, R16.2, U3.1
/Main/SVF/LP_R: C4.1, R8.1, R21.2, U3.7
/Main/VCA (K)/VCA-K_CTRL: R23.1, R24.1, R55.1, R56.1, R100.2, U4.1
/Main/VCA (Q)/VCA-Q_CTRL: R73.1, R74.1, U4.6 (-), U4.7
/Main/VCA control/+5V_COMP: D2.2 (K), R37.1, R39.1, R40.1, R101.2, R102.1, U12.1 (K)
/Main/VCA control/RECT_AVG: C13.1, R30.2, U5.2 (-)
/Main/VCA control/RECT_FAST: R31.2, R32.2, R33.1, R35.1, R36.1, U5.3 (+)
BP_TMUX_L: J2.5, R15.1
BP_TMUX_R: J2.6, R20.1
Bypass_TMUX_L: J2.9, R17.1
Bypass_TMUX_R: J2.10, R22.1
ENV_DEPTH: J2.15, RV3.2
ENV_OUT: J2.13, R96.1, R97.1
GNDA: C5.2, C6.1, C7.2, C8.1, C13.2, C14.1, C15.2, C16.2, C17.1, C19.2, C20.1, C23.2, C24.1, C25.1, D2.1 (A), J1.1, J6.1, J10.10, JP1.2 (B), JP2.2 (B), R6.2, R12.2, R29.1, R33.2, R42.2, R43.2, R44.1, R48.1, R50.1, R51.2, R52.2, R61.1, R62.1, R66.1, R68.1, R69.2, R71.2, R79.1, R80.1, R84.1, R86.1, R87.2, R88.2, R92.2, R99.1, R103.2, RV3.1, U2.3 (+), U2.5 (+), U3.3 (+), U3.5 (+), U5.4 (V-), U6.3 (+), U6.5 (+), U10.3 (A), U12.3 (A)
HP_TMUX_L: J2.3, R13.1
HP_TMUX_R: J2.4, R19.1
LP_TMUX_L: J2.7, R16.1
LP_TMUX_R: J2.8, R21.1
unnamed: C9.1, R46.1
unnamed: C9.2, R54.2, U7.8
unnamed: C10.1, R49.1
unnamed: C10.2, R53.2, U7.9
unnamed: C11.1, R64.1
unnamed: C11.2, R70.2, U8.8
unnamed: C12.1, R67.1
unnamed: C12.2, R72.2, U8.9
unnamed: C18.2, R38.2, R39.2, U5.1
unnamed: C21.1, R82.1
unnamed: C21.2, R90.2, U9.8
unnamed: C22.1, R85.1
unnamed: C22.2, R89.2, U9.9
unnamed: D1.2 (A), R34.1
unnamed: C14.2, D1.1 (K), RV3.3
unnamed: C18.1, D2.3 (COM), R43.1, U5.5 (+)
unnamed: D3.2 (A), J5.2
unnamed: D3.1 (K), J5.1
unnamed: D4.1 (A1), J4.1
unnamed: D4.3 (A2), J4.3
unnamed: D4.2 (K), J4.2
unnamed: J2.16, JP1.1 (A)
unnamed: J3.10, JP2.1 (A)
unnamed: R23.2, U7.1
unnamed: R24.2, U7.16
unnamed: R25.2, R27.1
unnamed: R26.2, R28.1
unnamed: R34.2, R37.2, U5.7
unnamed: R35.2, R36.2, R38.1
unnamed: R51.1, U7.5, U7.7
unnamed: R52.1, U7.10, U7.12
unnamed: R55.2, U8.1
unnamed: R56.2, U8.16
unnamed: R57.2, R59.1
unnamed: R58.2, R60.1
unnamed: R69.1, U8.5, U8.7
unnamed: R71.1, U8.10, U8.12
unnamed: R73.2, U9.1
unnamed: R74.2, U9.16
unnamed: R75.2, R77.1
unnamed: R76.2, R78.1
unnamed: R87.1, U9.5, U9.7
unnamed: R88.1, U9.10, U9.12
unnamed: R93.1, R95.2, RV1.1
unnamed: R94.1, RV2.3
unnamed: R95.1, R98.1, RV1.2
unnamed: R1.1, R2.2, R3.2, U1.2 (-)
unnamed: R7.1, R8.2, R9.2, U1.6 (-)
unnamed: R96.2, R97.2, R98.2, U4.3 (+)
unnamed: R99.2, R100.1, U4.2 (-)
unnamed: RV2.2, U4.5 (+)
unnamed: R40.2, R42.1, U5.6 (-)
unnamed: R47.2, R50.2, U7.14 (+)
unnamed: R44.2, U7.13 (-)
unnamed: R28.2, U7.15 (DIODE_BIAS)
unnamed: R45.2, R48.2, U7.3 (+)
unnamed: R29.2, U7.4 (-)
unnamed: R27.2, U7.2 (DIODE_BIAS)
unnamed: R65.2, R68.2, U8.14 (+)
unnamed: R62.2, U8.13 (-)
unnamed: R60.2, U8.15 (DIODE_BIAS)
unnamed: R63.2, R66.2, U8.3 (+)
unnamed: R61.2, U8.4 (-)
unnamed: R59.2, U8.2 (DIODE_BIAS)
unnamed: R83.2, R86.2, U9.14 (+)
unnamed: R80.2, U9.13 (-)
unnamed: R78.2, U9.15 (DIODE_BIAS)
unnamed: R81.2, R84.2, U9.3 (+)
unnamed: R79.2, U9.4 (-)
unnamed: R77.2, U9.2 (DIODE_BIAS)
unnamed: R41.2, R91.1, RV1.3, RV2.1, U10.1 (K)
unnamed: R91.2, R92.1, U10.2 (REF)
unnamed: R102.2, R103.1, U12.2 (REF)
RECT: J3.7, R30.1, R31.1, R32.1
SUM_OUT_L: J3.5, R14.1, U6.1
SUM_OUT_R: J3.6, R18.1, U6.7
SUM_TMUX_L: J2.11, R14.2, U6.2 (-)
SUM_TMUX_R: J2.12, R18.2, U6.6 (-)
SVF_IN_L: J3.3, R1.2, R17.2
SVF_IN_R: J3.4, R7.2, R22.2

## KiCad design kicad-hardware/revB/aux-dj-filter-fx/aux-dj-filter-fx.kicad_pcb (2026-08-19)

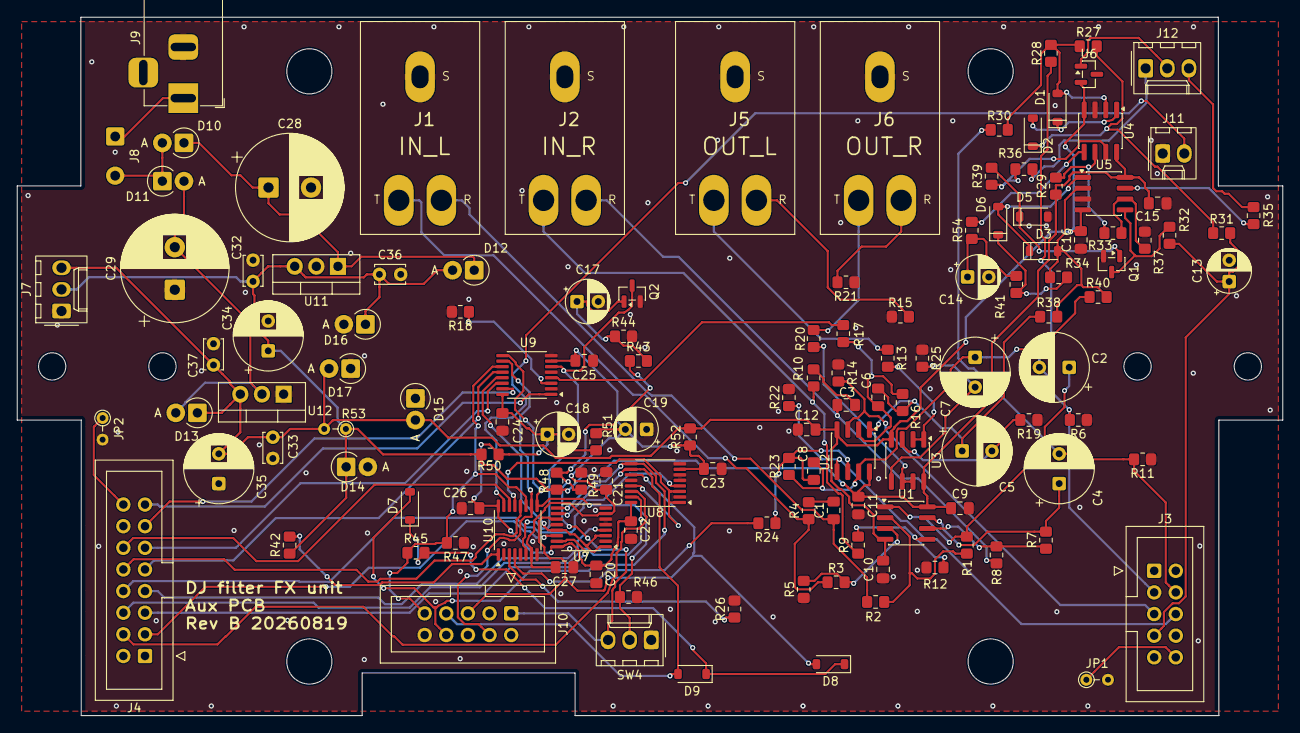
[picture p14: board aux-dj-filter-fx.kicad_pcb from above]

Board: 2 copper layers, 148.6 x 82.0 mm, 134 parts (0 on the bottom side), 87 nets.

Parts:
C1, C3: 220p, NP0; C_0805_2012Metric_Pad1.18x1.45mm_HandSolder
C2, C4, C5, C7: 22u, 25V; CP_Radial_D8.0mm_P3.50mm
C6, C8: 47p, NP0; C_0805_2012Metric_Pad1.18x1.45mm_HandSolder
C9, C10, C11, C12, C15, C16, C20, C21, C22, C23, C24, C25, C26, C27: 100n; C_0805_2012Metric_Pad1.18x1.45mm_HandSolder
C13, C14: 1u, 25V; CP_Radial_D5.0mm_P2.50mm
C17, C18, C19: 10u, 25V; CP_Radial_D5.0mm_P2.50mm
C28, C29: 1000u, 35V; CP_Radial_D12.5mm_P5.00mm
C32: 100n; C_Disc_D3.4mm_W2.1mm_P2.50mm
C33: 1u; C_Disc_D3.4mm_W2.1mm_P2.50mm
C34, C35: 220u, 25V; CP_Radial_D8.0mm_P3.50mm
C36, C37: 1u, TH; C_Disc_D3.4mm_W2.1mm_P2.50mm
D1, D2, D3, D5, D6: MMSD4148; D_SOD-123_K-mark
D7, D8, D9: MMSD4148; D_SOD-123
D10, D11, D12, D13, D14, D15: 1N4002; D_DO-41_SOD81_P2.54mm_Vertical_AnodeUp
D16, D17: 18V, 1W, TH; D_DO-41_SOD81_P2.54mm_Vertical_AnodeUp
J1: IN_L; Generic_6.35mm_TRS_3pins
J2: IN_R; Generic_6.35mm_TRS_3pins
J3: CONN_SIG; IDC-Header_2x05_P2.54mm_Vertical
J4: SW_CONN; IDC-Header_2x08_P2.54mm_Vertical
J5: OUT_L; Generic_6.35mm_TRS_3pins
J6: OUT_R; Generic_6.35mm_TRS_3pins
J7: PW_CONN; Molex_KK-254_AE-6410-03A_1x03_P2.54mm_Vertical
J8: FUSE_SW; SolderWire-0.5sqmm_1x02_P4.6mm_D0.9mm_OD2.1mm
J9: 16VAC; BarrelJack_Horizontal
J10: PHYSW_CONN; IDC-Header_2x05_P2.54mm_Vertical
J11: Conn_01x02_Pin; Molex_KK-254_AE-6410-02A_1x02_P2.54mm_Vertical
J12: Conn_01x03_Pin; Molex_KK-254_AE-6410-03A_1x03_P2.54mm_Vertical
JP1, JP2: Jumper_2_Small_Open; R_Axial_DIN0204_L3.6mm_D1.6mm_P2.54mm_Vertical
Q1, Q2: MMBT3904; SOT-23
R1, R5, R7, R12, R33, R49: 4K7; R_0805_2012Metric_Pad1.20x1.40mm_HandSolder
R2, R3, R8, R9, R42: 15K; R_0805_2012Metric_Pad1.20x1.40mm_HandSolder
R4, R10, R13, R15, R20, R21: 100R; R_0805_2012Metric_Pad1.20x1.40mm_HandSolder
R6, R11, R14, R19, R22, R25, R35, R36, R44, R48: 10K; R_0805_2012Metric_Pad1.20x1.40mm_HandSolder
R16, R23, R29: 6K8; R_0805_2012Metric_Pad1.20x1.40mm_HandSolder
R17, R24: 3K3; R_0805_2012Metric_Pad1.20x1.40mm_HandSolder
R18, R26, R28, R30, R47: 47K; R_0805_2012Metric_Pad1.20x1.40mm_HandSolder
R27: 68K; R_0805_2012Metric_Pad1.20x1.40mm_HandSolder
R31, R41: 1K8; R_0805_2012Metric_Pad1.20x1.40mm_HandSolder
R32, R54: 470K; R_0805_2012Metric_Pad1.20x1.40mm_HandSolder
R34: 51K; R_0805_2012Metric_Pad1.20x1.40mm_HandSolder
R37: 220R; R_0805_2012Metric_Pad1.20x1.40mm_HandSolder
R38, R40: 100K; R_0805_2012Metric_Pad1.20x1.40mm_HandSolder
R39, R43: 39K; R_0805_2012Metric_Pad1.20x1.40mm_HandSolder
R45, R46: 22K; R_0805_2012Metric_Pad1.20x1.40mm_HandSolder
R50, R52: 5K1; R_0805_2012Metric_Pad1.20x1.40mm_HandSolder
R51: 33K; R_0805_2012Metric_Pad1.20x1.40mm_HandSolder
R53: 1M, TH; R_Axial_DIN0204_L3.6mm_D1.6mm_P2.54mm_Vertical
SW4: ATTN_SW; Molex_KK-254_AE-6410-03A_1x03_P2.54mm_Vertical
U1, U2, U3: RC4580; SOIC-8_3.9x4.9mm_P1.27mm
U4, U5: TL072; SOIC-8_3.9x4.9mm_P1.27mm
U6: LM4040DBZ-2.0; SOT-23
U7, U8, U9, U10: TMUX4053; TSSOP-16_4.4x5mm_P0.65mm
U11: L7815; TO-220-3_Vertical
U12: L7915; TO-220-3_Vertical

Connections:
+11.5V: C18.1, C20.1, C22.1, C24.1, C26.1, R50.2, R51.1, U7.16 (VDD), U8.16 (VDD), U9.16 (VDD), U10.16 (VDD)
+15V: C9.1, C11.1, C15.1, C32.1, C34.1, C36.1, D12.2 (A), D14.1 (K), D16.1 (K), J7.2, R29.1, R42.1, R48.1, R50.1, R53.1, U1.8 (V+), U2.8 (V+), U3.8 (V+), U4.8 (V+), U5.8 (V+), U11.3 (OUT)
-11.5V: C19.2, C21.2, C23.2, C25.2, C27.2, R51.2, R52.1, U7.7 (VEE), U8.7 (VEE), U9.7 (VEE), U10.7 (VEE)
-15V: C10.2, C12.2, C16.2, C33.2, C35.2, C37.2, D13.1 (K), D15.2 (A), D17.2 (A), J7.3, R52.2, R53.2, U1.4 (V-), U2.4 (V-), U3.4 (V-), U4.4 (V-), U5.4 (V-), U6.2 (A), U12.3 (VO)
/Auxiliary/IO/ATTN_L: R17.2, U9.4 (C)
/Auxiliary/IO/ATTN_Ly: R18.1, U9.3 (C1)
/Auxiliary/IO/ATTN_R: R24.2, U10.4 (C)
/Auxiliary/IO/ATTN_Ry: R26.1, U10.3 (C1)
/Auxiliary/IO/IN_L_C: C1.1, J1.R, R2.1
/Auxiliary/IO/IN_L_H: J1.T, R3.1, R4.1
/Auxiliary/IO/IN_R_C: C3.1, J2.R, R8.1
/Auxiliary/IO/IN_R_H: J2.T, R9.1, R10.1
/Auxiliary/IO/LED_L_POST: C5.1, C6.2, R16.1, R38.1, U2.1
/Auxiliary/IO/LED_R_POST: C7.1, C8.2, R23.1, R40.1, U2.7
/Auxiliary/IO/OUT_L_C: J5.R, R15.2
/Auxiliary/IO/OUT_L_H: J5.T, R13.1
/Auxiliary/IO/OUT_R_C: J6.R, R21.2
/Auxiliary/IO/OUT_R_H: J6.T, R20.1
/Auxiliary/LFO_LED: J11.2, U10.15 (B)
/Auxiliary/LFO_LED_I: R42.2, U10.1 (B1)
/Auxiliary/Power supply/PS_AC1: D10.2 (A), D11.1 (K), J8.2
/Auxiliary/Swtich/+5V_LOGIC: J10.1, R43.1, R48.2, R49.1, SW4.3 (C)
/Auxiliary/Swtich/ATTN_LOGIC: R46.2, SW4.2 (B), U9.9 (S3), U10.9 (S3)
/Auxiliary/Swtich/BPF_LOGIC: D9.2 (A), J10.7, U7.10 (S2), U8.10 (S2)
/Auxiliary/Swtich/Bypass_LOGIC: J10.9, R45.1, R47.2, U9.11 (S1), U10.11 (S1)
/Auxiliary/Swtich/Bypass_override: D7.1 (K), D8.1 (K), D9.1 (K), R45.2
/Auxiliary/Swtich/ENV_LOGIC: J10.4, U9.10 (S2), U10.10 (S2)
/Auxiliary/Swtich/FILTER-BUS_L: U7.1 (B1), U7.3 (C1), U7.13 (A1), U9.13 (A1)
/Auxiliary/Swtich/FILTER-BUS_R: U8.1 (B1), U8.3 (C1), U8.13 (A1), U10.13 (A1)
/Auxiliary/Swtich/HPF_LOGIC: D8.2 (A), J10.5, U7.11 (S1), U8.11 (S1)
/Auxiliary/Swtich/LPF_LOGIC: D7.2 (A), J10.8, U7.9 (S3), U8.9 (S3)
/Auxiliary/Swtich/STARTUP: Q2.3 (C), U9.6 (INH), U10.6 (INH)
BP_TMUX_L: J4.5, U7.15 (B)
BP_TMUX_R: J4.6, U8.15 (B)
Bypass_TMUX_L: J4.9, U9.12 (A0)
Bypass_TMUX_R: J4.10, U10.12 (A0)
ENV_DEPTH: J4.15, U9.1 (B1)
ENV_OUT: J4.13, U9.15 (B)
GNDA: C9.2, C10.1, C11.2, C12.1, C13.2, C14.2, C15.2, C16.1, C17.2, C18.2, C19.1, C20.2, C21.1, C22.2, C23.1, C24.2, C25.1, C26.2, C27.1, C28.2, C29.1, C32.2, C33.1, C34.2, C35.1, C36.2, C37.1, D5.2 (A), D14.2 (A), D15.1 (K), D16.2 (A), D17.1 (K), J1.S, J2.S, J5.S, J6.S, J7.1, J9.2, J10.10, J11.1, JP1.2 (B), JP2.2 (B), Q1.2 (E), Q2.2 (E), R5.1, R6.1, R11.1, R12.1, R14.1, R15.1, R18.2, R19.1, R21.1, R22.1, R25.1, R26.2, R37.2, R44.2, R46.1, R47.1, R49.2, SW4.1 (A), U4.3 (+), U5.3 (+), U7.2 (B0), U7.5 (C0), U7.6 (INH), U7.8 (VSS), U7.12 (A0), U8.2 (B0), U8.5 (C0), U8.6 (INH), U8.8 (VSS), U8.12 (A0), U9.2 (B0), U9.5 (C0), U9.8 (VSS), U10.5 (C0), U10.8 (VSS), U11.2 (GND), U12.1 (GND)
HP_TMUX_L: J4.3, U7.14 (A)
HP_TMUX_R: J4.4, U8.14 (A)
LP_TMUX_L: J4.7, U7.4 (C)
LP_TMUX_R: J4.8, U8.4 (C)
unnamed: C1.2, R4.2
unnamed: C2.1, R1.2, U1.1
unnamed: C3.2, R10.2
unnamed: C4.1, R7.2, U1.7
unnamed: C14.1, R41.2, R54.1
unnamed: D1.2 (A), R27.1, R28.2, R30.2, U4.2 (-)
unnamed: D1.1 (K), D2.2 (A), U4.1
unnamed: D2.1 (K), R27.2, R31.1
unnamed: D3.2 (A), R34.1, R38.2, R40.2, U5.2 (-)
unnamed: D3.1 (K), D6.2 (A), U5.1
unnamed: D5.1 (K), Q1.1 (B), R39.2
unnamed: D6.1 (K), R34.2, R41.1
unnamed: C28.1, D10.1 (K), D12.1 (K), U11.1 (IN)
unnamed: C29.2, D11.2 (A), D13.2 (A), U12.2 (VI)
unnamed: J3.10, JP1.1 (A)
unnamed: J4.16, JP2.1 (A)
unnamed: J8.1, J9.1
unnamed: J12.1, R36.2
unnamed: J12.2, U6.1 (K)
unnamed: J12.3, R35.2
unnamed: Q1.3 (C), R32.2, U5.5 (+)
unnamed: C17.1, Q2.1 (B), R43.2, R44.1
unnamed: R35.1, U5.7
unnamed: R36.1, R39.1, U4.7
unnamed: R3.2, R5.2, U1.3 (+)
unnamed: R1.1, R2.2, U1.2 (-)
unnamed: R9.2, R12.2, U1.5 (+)
unnamed: R7.1, R8.2, U1.6 (-)
unnamed: C6.1, R16.2, R17.1, U2.2 (-)
unnamed: C8.1, R23.2, R24.1, U2.6 (-)
unnamed: C5.2, R19.2, U3.3 (+)
unnamed: R13.2, U3.1, U3.2 (-)
unnamed: C7.2, R25.2, U3.5 (+)
unnamed: R20.2, U3.6 (-), U3.7
unnamed: R54.2, U4.5 (+)
unnamed: R29.2, R33.1, U4.6 (-)
unnamed: R33.2, R37.1, U5.6 (-)
RECT: C13.1, J3.7, R31.2, R32.1
SUM_OUT_L: J3.5, R14.2, U2.3 (+)
SUM_OUT_R: J3.6, R22.2, U2.5 (+)
SUM_TMUX_L: J4.11, U9.14 (A)
SUM_TMUX_R: J4.12, U10.14 (A)
SVF_IN_L: C2.2, J3.3, R6.2, R28.1
SVF_IN_R: C4.2, J3.4, R11.2, R30.1

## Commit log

2026-08-17 Add pdf and svg files for schematic
2026-08-19 Rev B update
    [LED_rect.kicad_sch, aux-dj-filter-fx.kicad_pcb, aux-dj-filter-fx.kicad_sch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]
2026-08-19 Documents update
    [aux-dj-filter-fx.kicad_pcb, main-dj-filter-fx.kicad_pcb]
